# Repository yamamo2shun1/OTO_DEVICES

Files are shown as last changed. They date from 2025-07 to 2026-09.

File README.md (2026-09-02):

# JUMBLEQ

JUMBLEQ logo

[Official Website](https://jumbleq.io/) · [日本語](https://jumbleq.io/ja/)

JUMBLEQ beta prototype

“JUMBLEQ” is short for “jumbled equipment.”

JUMBLEQ is a faderless stereo digital audio mixer that replaces the traditional channel faders found on DJ mixers with magnetic switches. The switches behave like faders while enabling a compact and unconventional control layout.

Each of the two analog stereo inputs and two USB stereo inputs can be routed to Channel Fader A, Channel Fader B, or THRU. The USB audio I/O can also be used as a send/return path, allowing a USB host device to operate as an external effects processor.

As a USB Audio Class 2.0 interface, JUMBLEQ provides 4-in/4-out audio at 24-bit, 48 kHz or 96 kHz. It is USB class-compliant and can be used with Windows, macOS, iPhone, iPad, and Android devices without a device-specific driver.

## Key Features

- Faderless mixing with 10 magnetic switches and 12 potentiometers
- Flexible stereo input routing: assign each of the two analog and two USB inputs to Channel Fader A, Channel Fader B, or THRU
- 4-in/4-out USB Audio Class 2.0 at 24-bit, 48 kHz or 96 kHz
- USB audio send/return routing for external effects processing
- USB MIDI control and the browser-based JUMBLEQ Configurator
- Built-in UF2 bootloader for drag-and-drop firmware updates

## Documentation

See the [JUMBLEQ Documentation](./Docs/README.md) for the complete documentation index.

### User Guide

- [Operation Guide](./Docs/user-guide/operation-guide.md)
- [Firmware update](./Docs/user-guide/firmware-update.md)
- [JUMBLEQ Configurator](./Docs/user-guide/configurator.md)
- [Notes for Windows users](./Docs/user-guide/windows.md)

### Technical Reference

- [Audio specifications](./Docs/reference/audio-spec.md)
- [Hardware and PCB modules](./Docs/reference/hardware.md)
- [Block diagram and audio signal flow](./Docs/reference/signal-flow.md)
- [MIDI reference](./Docs/reference/midi/README.md)

### Development

- [Development environment](./Docs/development/environment.md)
- [STM32CubeIDE projects](./STM32CubeIDE/README.md)
- [SigmaStudio+ project](./SigmaStudio+/README.md)
- [Build and UF2 generation](./Docs/development/build-and-uf2.md)
- [ST-LINK debug configuration](./STM32CubeIDE/docs/Debug_Configuration-STLINK.md)
- [J-Link debug configuration](./STM32CubeIDE/docs/Debug_Configuration-JLINK.md)
- [STM32H7S3 errata](./Docs/development/errata.md)

## Public Website

Visit the [official JUMBLEQ website](https://jumbleq.io/) for an overview of the product, its features, controls, and specifications.

The Astro source is maintained in [`Site`](./Site/) and deployed to GitHub Pages by [the Pages workflow](./.github/workflows/pages.yml).

## Repository Contents

- [`Docs`](./Docs/) — user guides, technical reference, and development notes
- [`Site`](./Site/) — Astro source for the public JUMBLEQ website
- [`STM32CubeIDE`](./STM32CubeIDE/) — MCU application, bootloader, and external memory loader projects
- [`SigmaStudio+`](./SigmaStudio+/) — ADAU1466 DSP project and exported code
- [`Max`](./Max/) — alternative Max Standalone and Max for Live versions of JUMBLEQ Configurator
- [`Plasticity`](./Plasticity/) — enclosure CAD data and printable parts
- [`Logo`](./Logo/) — JUMBLEQ logo and icon artwork
- [`UI_Design`](./UI_Design/) — panel and control-layout artwork

## Related Repositories

- [JUMBLEQ Configurator](https://github.com/yamamo2shun1/JUMBLEQ-Configurator) — browser-based JUMBLEQ Configurator

## Gallery

- [Beta Prototype](./Gallery/beta_prototype.md)
- [Alpha Prototype](./Gallery/alpha_prototype.md)
- [Functional Prototype](./Gallery/functional_prototype.md)
- [Early Prototype](./Gallery/early_prototype.md)
- [Proof of Concept](./Gallery/proof_of_concept.md)

## License

Unless otherwise noted below, this project is licensed under the [MIT License](./LICENSE.md).

- Hardware design sources in [`Plasticity`](./Plasticity/) are licensed under the [CERN Open Hardware Licence Version 2 – Permissive](./Plasticity/LICENSE) (`CERN-OHL-P-2.0`).
- Panel and control-layout design sources in [`UI_Design`](./UI_Design/) are licensed under the [CERN Open Hardware Licence Version 2 – Permissive](./UI_Design/LICENSE) (`CERN-OHL-P-2.0`).

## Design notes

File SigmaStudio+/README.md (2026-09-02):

# SigmaStudio+ Project

This directory contains the SigmaStudio+ project and generated files for the SigmaDSP ADAU1466.

## Updating the DSP Project

After modifying [`JUMBLEQ_DSP.ssprj`](./JUMBLEQ_DSP.ssprj), perform the following operations in SigmaStudio+:

1. Run **Link Compile**.
2. Run **Export System Files**.

The exported files are written to [`exported_code`](./exported_code/).

## Integrating Changes into JUMBLEQ

To include the updated DSP project in JUMBLEQ, copy the following generated header files from [`exported_code`](./exported_code/) to [`STM32CubeIDE/JUMBLEQ/Appli/Core/Inc`](../STM32CubeIDE/JUMBLEQ/Appli/Core/Inc/), replacing the existing files:

- `JUMBLEQ_DSP_ADAU146xSchematic_1.h`
- `JUMBLEQ_DSP_ADAU146xSchematic_1_Defines.h`
- `JUMBLEQ_DSP_ADAU146xSchematic_1_PARAM.h`

## Sample Rate and ASRC Routing

The ADAU1466 DSP core and the AK4619 audio codec interface always operate at 96 kHz. The STM32-to-ADAU1466 serial audio interface follows the USB Audio sample rate and operates at either 48 kHz or 96 kHz.

At 48 kHz, the ADAU1466 ASRCs convert both directions between the STM32-side 48 kHz domain and the DSP-core 96 kHz domain:

```text
STM32 48 kHz -> ASRC input  -> DSP core 96 kHz
STM32 48 kHz <- ASRC output <- DSP core 96 kHz
```

At 96 kHz, the STM32 serial interface and DSP core run at the same sample rate, so the firmware selects the direct paths and bypasses the ASRCs:

```text
STM32 96 kHz -> DSP core 96 kHz
STM32 96 kHz <- DSP core 96 kHz
```

The firmware changes only the STM32-side serial clock and the ASRC/direct routing when the USB sample rate changes. It does not reload the SigmaStudio+ program or change the DSP-core or AK4619 sample rate. Therefore, keep the SigmaStudio+ project configured for 96 kHz and preserve both the direct and ASRC signal paths when modifying the schematic.

## DSP Schematic

### USB Inputs

ss_input1

### Analog Inputs, Line/Phono Selection, Phono EQ and DVS

ss_input2

### Channel Fader Routing

ss_sw1

### THRU Routing

ss_sw2

### Channel Fader Control

ss_fader

### VU Meter Readback

ss_read

### Analog Outputs and Dry/Wet Control

ss_output1

### Headphone Output and Monitor Selection

ss_output2

### USB Outputs and Send Selection

ss_output3

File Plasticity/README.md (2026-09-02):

# JUMBLEQ Enclosure CAD

This directory contains the source and exported CAD data for the JUMBLEQ enclosure, plates, and printable parts.

## License

Copyright (c) 2025 Shunichi Yamamoto.

Unless otherwise noted, the hardware design sources in this directory are licensed under the [CERN Open Hardware Licence Version 2 – Permissive](./LICENSE) (`CERN-OHL-P-2.0`).

You may redistribute and modify these sources and make products using them under the terms of the CERN-OHL-P v2.

These sources are distributed **WITHOUT ANY EXPRESS OR IMPLIED WARRANTY, INCLUDING OF MERCHANTABILITY, SATISFACTORY QUALITY AND FITNESS FOR A PARTICULAR PURPOSE**. See the CERN-OHL-P v2 for applicable conditions.

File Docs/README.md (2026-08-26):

# JUMBLEQ Documentation

This directory contains user guides, technical reference material, and development notes for JUMBLEQ.

## User Guide

- [Operation Guide](./user-guide/operation-guide.md) — controls, signal routing, and device operation
- [Firmware update](./user-guide/firmware-update.md) — update JUMBLEQ using the built-in UF2 bootloader
- [JUMBLEQ Configurator](./user-guide/configurator.md) — change device settings from the Web app or alternative Max versions
- [Notes for Windows users](./user-guide/windows.md) — low-latency audio driver options

## Technical Reference

- [Audio specifications](./reference/audio-spec.md)
- [Hardware](./reference/hardware.md) — main components and PCB modules
- [Signal flow](./reference/signal-flow.md) — hardware block diagram and audio routing
- [MIDI](./reference/midi/README.md) — receive and transmit specifications

## Development

- [Development environment](./development/environment.md)
- [ST-LINK debug configuration](../STM32CubeIDE/docs/Debug_Configuration-STLINK.md)
- [J-Link debug configuration](../STM32CubeIDE/docs/Debug_Configuration-JLINK.md)
- [Build and UF2 generation](./development/build-and-uf2.md)
- [STM32H7S3 errata](./development/errata.md)
- [STM32CubeIDE project overview](../STM32CubeIDE/README.md)

## Project History

See the [Gallery](../Gallery/) for photographs and notes from each prototype stage.

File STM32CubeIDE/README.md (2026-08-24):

# STM32CubeIDE Projects

This STM32CubeIDE workspace contains the firmware projects for the JUMBLEQ hardware.
All projects target the **STM32H7S3Z8T6** on the [STM32H7S3 Development Board](https://github.com/YamamotoWorksDev/STM32H7S3_Dev_Board).

For the debug probe settings used with these projects, see [Debug Configuration for ST-LINK](docs/Debug_Configuration-STLINK.md) and [Debug Configuration for J-Link](docs/Debug_Configuration-JLINK.md). For RTT output, see the J-Link RTT Viewer setup guides for [`JUMBLEQ`](docs/RTT_Viewer-JUMBLEQ.md) and [`LED_BLINK_APP_JLINK`](docs/RTT_Viewer-LED_BLINK_APP_JLINK.md).

## Projects

### `JUMBLEQ`

The main firmware for JUMBLEQ.

- Runs USB, audio, LED, ADC, and OLED processing on FreeRTOS
- Provides USB Audio Class 2.0 and USB MIDI using TinyUSB
- Controls the AK4619 audio codec and ADAU1466 DSP
- Provides the user interface through the OLED, LEDs, and hardware controls
- Saves settings to EEPROM and restores them at startup

The buildable STM32CubeIDE project is located in `JUMBLEQ/Appli`.
The application is configured to run from external flash at `0x90010000`. The post-build step generates BIN and UF2 files. See [J-Link RTT Viewer Setup for JUMBLEQ](docs/RTT_Viewer-JUMBLEQ.md) for its RTT debug output configuration.

### `LED_BLINK_APP`

A minimal test application for verifying basic board operation and application startup from external flash.
It turns LED1 and LED2 on and off in sequence at 500 ms intervals.

The buildable STM32CubeIDE project is located in `LED_BLINK_APP/Appli`.
Like `JUMBLEQ`, the application is configured to run from external flash at `0x90010000`. The post-build step generates a UF2 file.

### `LED_BLINK_APP_JLINK`

A J-Link debug variant of `LED_BLINK_APP` that reports the LED1 and LED2 state changes through SEGGER RTT with timestamps.

The buildable STM32CubeIDE project is located in `LED_BLINK_APP_JLINK/Appli`. The RTT control block is placed in a non-cacheable RAM region so RTT remains coherent while the Cortex-M7 data cache is enabled. See [J-Link RTT Viewer Setup](docs/RTT_Viewer-LED_BLINK_APP_JLINK.md) for the viewer configuration.

### `MX25UW25645GXDI00_STM32H7S3Z8T`

The bootloader and external memory loader for the **MX25UW25645GXDI00** external flash device.

- `Boot`: Bootloader that writes UF2 files over USB Mass Storage Class
  - Enters UF2 update mode when started while SW3 is held down
  - Jumps to the application in external flash during a normal startup
- `ExtMemLoader`: Loader that allows STM32CubeProgrammer and STM32CubeIDE to access the external flash
- `uf2conv.py`: Tool that converts BIN files to UF2 format

#### Boot Build Configuration

The `Boot` project must be built with compiler optimization enabled to fit in the internal flash of the STM32H7S3Z8T6. The `Debug` configuration uses `-O0`, which produces an image that is too large and causes the build to fail. Use the `Release` configuration, which uses `-Os` to optimize the image for size.

In STM32CubeIDE, select `Project > Build Configurations > Set Active > Release` before building the `Boot` project.

For bootloader details, see [`docs/UF2_BOOTLOADER_SPEC.md`](MX25UW25645GXDI00_STM32H7S3Z8T/docs/UF2_BOOTLOADER_SPEC.md).

## Project Relationships

`MX25UW25645GXDI00_STM32H7S3Z8T/Boot` handles startup and firmware updates, then runs `JUMBLEQ/Appli`, `LED_BLINK_APP/Appli`, or `LED_BLINK_APP_JLINK/Appli` from external flash.

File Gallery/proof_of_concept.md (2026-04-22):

# Proof of Concept
DSCF6165-2
DSCF6172-2
DSCF6176-2

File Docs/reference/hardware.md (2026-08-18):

# Hardware

## Main Components

- MCU: [STM32H7S3Z8](https://www.st.com/en/microcontrollers-microprocessors/stm32h7s3z8.html)
- DSP: [ADAU1466](https://www.analog.com/en/products/adau1466.html)
- Audio codec: [AK4619](https://www.akm.com/global/en/products/audio/audio-codec/ak4619vn/)
- Headphone DAC: [TAD5142](https://www.ti.com/product/TAD5142)
- Controls: 10 × [Gateron Low Profile Magnetic Jade Pro](https://www.gateron.com/products/gateron-full-pom-low-profile-magnetic-jade-pro-switch-set) switches and 12 × 10 kΩ potentiometers

## Original PCB Modules

- [STM32H7S3 Development Board](https://github.com/YamamotoWorksDev/STM32H7S3_Dev_Board)
- [AK4619 Audio Module](https://github.com/YamamotoWorksDev/AK4619_Module)
- [TAD5142 Headphone Module](https://github.com/YamamotoWorksDev/TAD5142_Module)
- [Magnetic Switch and Potentiometer Module](https://github.com/YamamotoWorksDev/MagneticSwitch_and_POT_Module)
- [JST PH2 Bus Module](https://github.com/YamamotoWorksDev/JST_PH2_BUS)

## Third-party Modules

- [0.96-inch 128 × 64 OLED display](https://akizukidenshi.com/catalog/g/g112031/)
- [SparkFun Qwiic OLED Display, 0.91-inch 128 × 32](https://www.sparkfun.com/sparkfun-qwiic-oled-display-0-91-in-128x32-lcd-24606.html)
- [SparkFun Qwiic EEPROM Breakout, 512 Kbit](https://www.sparkfun.com/sparkfun-qwiic-eeprom-breakout-512kbit.html)

See [Signal flow](./signal-flow.md) for the relationship between the main hardware blocks.

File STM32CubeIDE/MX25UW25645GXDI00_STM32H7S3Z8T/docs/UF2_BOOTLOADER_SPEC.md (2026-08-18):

# UF2 Bootloader Specification (MX25UW25645GXDI00_STM32H7S3Z8T)

Last updated: 2026-08-17

## Overview

- Target project: `MX25UW25645GXDI00_STM32H7S3Z8T`
- The current system uses a simple configuration that starts an application from external flash using execute-in-place (XIP).
- The UF2 bootloader adds firmware updates over USB Mass Storage Class (MSC).

## Confirmed Requirements

- Enter bootloader mode: power on the device by connecting USB while holding SW3
- USB mode: High Speed (HS)
- Image validation: CRC32 only
- Application location: fixed offset in external flash
- Volume label: `UF2BOOT`
- USB VID/PID: `0x31BF` / `0x0100`

## Purpose

- Receive a UF2 file over USB MSC and write it to the application region in external flash.
- Validate the application using CRC32, then start it using XIP.

## Startup Flow

1. Perform low-level initialization for the clock, MPU, and caches.
2. Initialize XSPI and ExtMem Manager.
3. Select the boot mode.
   - Enter UF2 mode when SW3 is held and USB is connected.
   - Otherwise, start the application.
4. In UF2 mode:
   - Start the USB MSC device.
   - Receive UF2 blocks and write them to external flash.
   - Update the metadata after successful CRC32 validation.
5. In normal mode:
   - Jump to the XIP application.

## Memory Map

- Internal flash
  - Bootloader
- External flash (32 MB = `0x0200_0000`)
  - META region: `0x9000_0000` - `0x9000_FFFF` (64 KB)
  - APP region: `0x9001_0000` - `0x9040_FFFF` (4 MB)
  - Reserved: `0x9041_0000` - `0x91FF_FFFF` (remaining space)

### Fixed Offsets

- `APP_OFFSET = 0x0001_0000` (64 KB)
- `APP_BASE = 0x9000_0000 + APP_OFFSET = 0x9001_0000`
- Set `EXTMEM_XIP_IMAGE_OFFSET` equal to `APP_OFFSET`.
- Set `EXTMEM_HEADER_OFFSET` to `0`.

The META region could be as small as 4 KB, but 64 KB is reserved to align it with an erase-block boundary.

## Erase and Write Strategy

- The device supports 4 KB sector erase and 64 KB block erase operations.
- Erase the APP region in 64 KB blocks to reduce update time.
- Allow 4 KB sector erase operations for small regions such as META.
- When receiving a UF2 file, pre-erase only the 64 KB blocks that correspond to the target address range.

## UF2 Processing

- Receive 512-byte UF2 blocks over USB MSC.
- Map each `targetAddr` to the APP region in external flash.
- Write each block as it is received.
- Calculate CRC32 after all blocks have been received.
- Update META after successful CRC32 validation.

## UF2 MSC Virtual Disk Layout

- Purpose: provide enough capacity to transfer a UF2 file of approximately 8 MB for a 4 MB application
- Disk size: 16 MB (16,384 KB)
- Sector size: 512 bytes
- Cluster size: 1 sector
- File system: FAT16
- Root directory entries: 64
- Volume label: `UF2BOOT`

### Generated Read-only Files

- `INFO_UF2.TXT`
  - Board name, build information, supported address range, and related information
- `INDEX.HTM`
  - Optional link to the product page or update instructions
- `CURRENT.UF2` (optional)
  - Used to read back the current application; omit it if this feature is not required

### Write Acceptance Rules

- Accept only blocks with valid UF2 magic values.
- Write only blocks whose `targetAddr` is within `APP_BASE .. APP_BASE + APP_SIZE - 1`.
- Ignore addresses outside this range and ordinary file-system writes.
- On the first write to an address, erase only the corresponding 64 KB block.
- Use `numBlocks` and `blockNo` to determine when reception is complete, then perform CRC32 validation.

## UF2 Generation and Installation

### Prerequisites

- Application link address: `0x90010000` (`APP_BASE`)
- Use `uf2conv.py` for UF2 conversion.
- Place `uf2families.json` in the same directory as `uf2conv.py`.
- Family ID: `STM32H7RS = 0x6db66083`

### 1. Convert ELF to BIN
```
arm-none-eabi-objcopy -O binary app.elf app.bin
```

### 2. Convert BIN to UF2
```
python uf2conv.py -c -b 0x90010000 -f STM32H7RS -o app.uf2 app.bin
```

### 3. Install the Firmware

1. Hold SW3 while powering on the device by connecting USB.
2. Wait for the `UF2BOOT` volume to mount on the host computer.
3. Drag and drop `app.uf2` onto `UF2BOOT`.
4. After the update completes, the bootloader automatically jumps to the application.

## CRC32 Metadata Specification

### Location

- META base address: `0x9000_0000`
- The first 256 bytes are used for metadata.

### Format (Little-endian)
```
typedef struct {
  uint32_t magic;       // 0x4D544131 ('MTA1')
  uint16_t version;     // 0x0001
  uint16_t header_size; // sizeof(MetaHeader) = 64
  uint32_t flags;       // bit0: valid
  uint32_t app_base;    // 0x90010000
  uint32_t app_size;    // max 0x00400000
  uint32_t app_crc32;   // CRC32 of the entire application
  uint32_t build_id;    // Optional build number or short Git hash
  uint32_t image_size;  // Number of bytes actually written
  uint32_t reserved[6]; // 0
} MetaHeader;
```

### Update Timing

- Calculate CRC32 after the complete UF2 image has been received.
- Update META with `flags.valid = 1` only if CRC32 validation succeeds.
- To update META, erase its 4 KB sector and write the first 256 bytes.

### Validation at Startup

- Check `magic`, `version`, and `header_size` at startup.
- If `flags.valid == 1` and `app_size` is within the maximum size, validate CRC32.
- Start the application using XIP when validation succeeds; enter UF2 mode when validation fails.

## LED Status Patterns

- Normal startup (jump to XIP application): turn on LED0 for 1 second, then turn it off.
- Waiting for UF2 (update mode entered with SW3): blink LED0 slowly at 1 Hz.
- Writing UF2: blink LED1 quickly at 4 Hz.
- Validating CRC32: breathe LED2 at 0.5 Hz.
- Validation successful / preparing to start: turn on LED0, LED1, and LED2 together for 200 ms, then turn them off.
- Validation failed / error: blink LED2 twice for 100 ms each, repeating every second.
- SW3 held without a USB connection (invalid): blink LED1 briefly three times.

## XIP Startup Strategy
- `VTOR = APP_BASE`
- `MSP = *(uint32_t*)APP_BASE`
- `PC  = *(uint32_t*)(APP_BASE + 4)`
- Clean and invalidate the caches before jumping to the application.

## Current Boot Implementation Review (2026-02-12)

- `BOOT_Application()` is implemented in `stm32_boot_xip.c`.
- `MapMemory()` calls `EXTMEM_MemoryMappedMode()` for every memory in `extmem_list_config`.
- If `EXTMEM_MEMORY_BOOTXIP` is unsupported, the bootloader reports `BOOT_ERROR_INCOMPATIBLEMEMORY`.
- `JumpToApplication()` performs the following operations in order:
  - Calls `EXTMEM_GetMapAddress(EXTMEM_MEMORY_BOOTXIP, &Application_vector)`.
  - Adds `EXTMEM_XIP_IMAGE_OFFSET` and `EXTMEM_HEADER_OFFSET`; both are currently undefined and therefore default to `0`.
  - Stops SysTick, I-Cache, and D-Cache.
  - Sets `VTOR`, sets `MSP`, and jumps to `PC`.
- `Boot/Core/Src/main.c` initializes the following components in order:
  - `MX_XSPI1_Init()`
  - `MX_EXTMEM_MANAGER_Init()`
  - `BOOT_Application()`
- The MPU configures the 32 MB region at `0x90000000` as executable and cacheable.
- The linker reserves 64 KB of internal flash starting at `0x08000000` for the bootloader.
- `extmem_list_config` is initialized for NOR SFDP, XSPI1, and 8-line mode.

## Remaining Work

1. Complete the boot-mode selection, USB MSC, UF2 writing, META update, and LED control implementation.

## Implementation Status (2026-02-12)

- Implemented the basic structure for boot-mode selection, UF2 parsing, external flash writes, META updates, and LED control.
- USB MSC operates in High Speed mode using TinyUSB.
- MSC presents a minimal 16 MB FAT16 virtual disk with read-only generated files.
- Confirmed CRC32 validation and the automatic jump to the application after a UF2 update.

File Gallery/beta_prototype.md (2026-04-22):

# Beta Prototype (firmware v0.9.10)
DSCF8296
DSCF8275
DSCF8300
DSCF8299
DSCF8316
DSCF8331

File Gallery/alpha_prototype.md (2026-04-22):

# Alpha Prototype (firmware v0.9.7)







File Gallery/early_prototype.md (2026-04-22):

# Early Prototype
DSCF6407
DSCF6405
DSCF6411
DSCF6414
DSCF6415
DSCF6416

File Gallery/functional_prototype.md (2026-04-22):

# Functional Prototype (firmware v0.9.4)
DSCF6900
DSCF6901
DSCF6902
DSCF6903
DSCF6906
DSCF6908
DSCF6910

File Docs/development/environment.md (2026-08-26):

# Development Environment

The project currently uses the following development tools and packages:

- IDE: [STM32CubeIDE](https://www.st.com/en/development-tools/stm32cubeide.html) 2.2.0
- Code generation and configuration: [STM32CubeMX](https://www.st.com/en/development-tools/stm32cubemx.html) 6.18.1
- Toolchain: GNU Tools for STM32 14.3.rel1.20251027-0700 (GCC 14.3.1)
- UF2 conversion: [Python](https://www.python.org/) 3.13.14
- MCU firmware package: STM32CubeH7RS v1.3.0
- DSP development: [SigmaStudio+](https://www.analog.com/en/resources/evaluation-hardware-and-software/embedded-development-software/sigmastudio-plus.html) 3.4.0
- Legacy Configurator development: [Max](https://cycling74.com/products/max-9) 9.1.5

See the [STM32CubeIDE project overview](../../STM32CubeIDE/README.md) for the firmware projects included in this repository. The Web Configurator is maintained separately in the [JUMBLEQ Configurator repository](https://github.com/yamamo2shun1/JUMBLEQ-Configurator).

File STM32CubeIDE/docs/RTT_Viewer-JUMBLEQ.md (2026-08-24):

# J-Link RTT Viewer Setup for `JUMBLEQ`

This guide describes the J-Link RTT Viewer settings used to monitor debug messages from `JUMBLEQ_Appli`.

## Prerequisites

- Build and program `JUMBLEQ_Appli` with `JUMBLEQ_Appli Debug (JLINK)`.
- Keep the target powered and allow the application to run.
- Install SEGGER J-Link Software and Documentation Pack, including J-Link RTT Viewer.

## Connection Settings

Open J-Link RTT Viewer and use the following configuration.

J-Link RTT Viewer configuration for JUMBLEQ

| Setting | Value |
| --- | --- |
| Connection to J-Link | `USB` |
| SN / Nickname | Disabled unless selecting a specific probe |
| Target Device | `STM32H7S3Z8` |
| Force go on connect | Disabled |
| Script file | Leave empty |
| Target Interface | `SWD` |
| Speed | `4000 kHz` |
| RTT Control Block | `Address` |
| RTT Control Block address | `0x20004200` |

Click **OK** to connect. Channel 0 displays firmware diagnostics while the application is running. The exact messages depend on the connected hardware and runtime activity. For example:

```text
EEPROM CAT24C512 detected on I2C2 (0x50)
[USB] loop=... ready=... idle=... lag=... max_gap=...
```

## Control Block Address

For the current Debug build, select **Address** and enter:

```text
0x20004200
```

In the current Debug build, `_SEGGER_RTT` occupies `0x4B8` bytes in the `.rtt` section starting at `0x20004200`. The linker places this section in DTCM, which is not affected by the Cortex-M7 data cache.

Unlike the fixed address used by `LED_BLINK_APP_JLINK`, the `JUMBLEQ_Appli` address follows the heap and stack allocation and can move when the linker layout changes. After such a change, use **Auto Detection** or confirm `_SEGGER_RTT` in `Debug/JUMBLEQ_Appli.map` and update the address.

## Troubleshooting

- If no output appears, resume the application in STM32CubeIDE; RTT output stops while the CPU is halted.
- Confirm that the selected device is `STM32H7S3Z8` and the interface is `SWD`.
- If the configured address no longer works after a layout change, try **Auto Detection** and check the map file.
- If more than one J-Link is connected, enable **SN / Nickname** and select the intended probe.
- Rebuild the application after changing its linker script, heap size, stack size, or RTT configuration.

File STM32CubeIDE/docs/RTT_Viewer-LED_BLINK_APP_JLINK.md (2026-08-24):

# J-Link RTT Viewer Setup for `LED_BLINK_APP_JLINK`

This guide describes the J-Link RTT Viewer settings used to monitor the LED state messages from `LED_BLINK_APP_JLINK_Appli`.

## Prerequisites

- Build and program `LED_BLINK_APP_JLINK_Appli` with its J-Link Debug configuration.
- Keep the target powered and allow the application to run.
- Install SEGGER J-Link Software and Documentation Pack, including J-Link RTT Viewer.

## Connection Settings

Open J-Link RTT Viewer and use the following configuration.

J-Link RTT Viewer configuration for LED_BLINK_APP_JLINK

| Setting | Value |
| --- | --- |
| Connection to J-Link | `USB` |
| SN / Nickname | Disabled unless selecting a specific probe |
| Target Device | `STM32H7S3Z8` |
| Force go on connect | Disabled |
| Script file | Leave empty |
| Target Interface | `SWD` |
| Speed | `4000 kHz` |
| RTT Control Block | `Address` |
| RTT Control Block address | `0x24071C00` |

Click **OK** to connect. Channel 0 displays messages similar to the following while the application is running:

```text
LED blink started
[0 ms] LED1 ON
[200 ms] LED2 ON
[400 ms] LED1 OFF
[600 ms] LED2 OFF
```

## Why a Fixed Address Is Used

The RTT control block and buffers are linked into the `RW_NONCACHEABLE` region beginning at `0x24071C00`. The application configures this 1 KiB region as non-cacheable before enabling the Cortex-M7 data cache, allowing both the target and J-Link to observe coherent RTT data.

If the RAM layout or linker script changes, confirm the address of `_SEGGER_RTT` in `Debug/LED_BLINK_APP_JLINK_Appli.map` before reconnecting RTT Viewer.

## Troubleshooting

- If no output appears, resume the application in STM32CubeIDE; RTT output stops while the CPU is halted.
- Confirm that the selected device is `STM32H7S3Z8`, the interface is `SWD`, and the control block address is exactly `0x24071C00`.
- If more than one J-Link is connected, enable **SN / Nickname** and select the intended probe.
- Rebuild the application after changing the linker script or RTT configuration.

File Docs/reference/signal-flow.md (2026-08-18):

# Signal Flow

## Hardware Block Diagram

JUMBLEQ hardware block diagram

## Audio Routing and Signal Flow

JUMBLEQ audio routing and signal-flow diagram

See [Audio specifications](./audio-spec.md) for the supported I/O formats and measured analog levels.

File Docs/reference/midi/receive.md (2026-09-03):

# MIDI Receive Specification

This document describes the MIDI receive specification based on the `JUMBLEQ/Appli/Core` implementation as of September 2026.

## 1. Overview

- Incoming MIDI messages are processed over USB MIDI.
- Incoming messages used to change UI settings are accepted only on **MIDI Ch. 15** (1-based channel numbering).

## 2. Program Change (Host -> Device)

### 2.1 Acceptance Conditions

- Program Change messages are accepted only on MIDI Ch. 15.
- Program Change messages on all other channels are ignored.

### 2.2 Program Change Map

| PC Number | Function |
|---:|---|
| 0/1 | Set the Ch. 1 input type (Line / Phono). |
| 2/3 | Set the Ch. 2 input type (Line / Phono). |
| 4/5/6/7 | Assign an input source (Ch. 1 / Ch. 2 / USB[1/2] / USB[3/4]) to Channel Fader A. |
| 8/9/10/11 | Assign an input source (Ch. 1 / Ch. 2 / USB[1/2] / USB[3/4]) to Channel Fader B. |
| 12/13/14/15 | Assign an input source (Ch. 1 / Ch. 2 / USB[1/2] / USB[3/4]) to Post Fader. |
| 16/17 | Disable or enable DVS mode for Ch. 1. |
| 18/19 | Disable or enable DVS mode for Ch. 2. |
| 20/21/22 | Select the Return source (USB[1/2] / USB[3/4] / None). |
| 23/24/25/26 | Select the headphone output source (FADER_A / FADER_B / THRU / MASTER). |
| 27/28 | Assign magnetic switch 2 to the auxiliary fade-down function for Channel Fader A or B. |
| 29/30 | Assign magnetic switch 3 to the auxiliary fade-down function for Channel Fader A or B. |
| 31/32 | Set the Channel Fader A direction (Normal / Reverse). |
| 33/34 | Set the Channel Fader B direction (Normal / Reverse). |
| 120/121 | Disable or enable Channel Fader curve edit mode. |
| 122/123 | Select the output mode (CC / Note) for magnetic controls and channel fader sensors. |
| 126 | Transmit a dump of the parameters currently configured on the device. |
| 127 | Save the current settings to EEPROM. |

Notes:

- `PC22` selects `None`, which disables the Return signal path.
- Auxiliary fade-down assignments for magnetic switches 2 and 3 take effect immediately when the Program Change message is received.
- The default assignments are Channel Fader A for magnetic switch 2 and Channel Fader B for magnetic switch 3.
- Direction can be configured independently for Channel Faders A and B and takes effect immediately. The default is Normal for both faders.
- Reverse inverts the final fader response for Fade Up and all Fade Down controls assigned to that fader, including auxiliary Fade Down controls. It does not change the live MIDI values transmitted by the individual magnetic sensors.
- `PC127` saves the complete device configuration listed in Section 5 to EEPROM, including the DVS enable states, Return and headphone source assignments, magnetic output mode, auxiliary fade-down assignments, Direction settings, and curves for Channel Faders A and B.
- `PC126` transmits the **current operating state (parameters eligible for saving)** rather than reading and transmitting the EEPROM contents.

## 3. Control Change (Host -> Device)

### 3.1 Acceptance Conditions

Control Change messages are accepted only when all of the following conditions are met:

- Channel Fader curve edit mode is enabled.
- The MIDI channel is Ch. 15.
- The CC number is supported (`20` or `21`).

### 3.2 Control Change Map

| CC Number | Parameter | CC Value |
|---:|---|---|
| 20 | `XFADE_CURVE_A` | 0 to 127 |
| 21 | `XFADE_CURVE_B` | 0 to 127 |

Curve response:

- `0` selects the strongest late-rise curve; the level changes mainly near the end of the key travel.
- `64` selects an exactly linear response across the full key travel.
- `127` selects the strongest early-rise curve; the level changes sharply near the start of the key travel.
- The late- and early-rise families use point-reflected exponential curves.
- The default value is `64` for both Channel Faders A and B.

## 4. `curve_edit_mode` (Channel Fader Curve Edit Mode) Behavior

- Use Program Change messages to enable or disable the mode (`PC121` ON / `PC120` OFF).
- While enabled, the main OLED shows the current curve CC values for Channel Faders A and B together with a graphical preview of each curve.
- While disabled, the main OLED uses its normal display and shows the gain values for each input and output channel.
- There is no automatic timeout.

## 5. EEPROM Storage and Startup Restore

- Save trigger: `PC127` on Ch. 15
- Saved parameters:
  - CH1/CH2 input types
  - Channel Fader A/B and Post Fader assignments
  - CH1/CH2 DVS enable states
  - Return source assignment
  - Headphone output source
  - Magnetic output mode (CC / Note)
  - Auxiliary fade-down assignments for magnetic switches 2 and 3
  - Direction settings (Normal / Reverse) for Channel Faders A/B
  - Curve settings for Channel Faders A/B
- EEPROM record version: `0x0007`

## 6. Implementation Notes

- Channel values in the implementation are zero-based (for example, `14` = MIDI Ch. 15).
- The Ch. 15 restrictions for incoming Program Change and Control Change messages are checked in their respective dispatch functions.
- Internally, `CC64` maps to zero exponential curvature. Values below it produce negative (late-rise) curvature, and values above it produce positive (early-rise) curvature. The absolute bipolar curve amount is cubed before it scales the exponent, providing finer adjustment around the linear midpoint while preserving the endpoint curves. The maximum curvature is calibrated so the `CC127` response reaches 90% output at 2% key travel. EEPROM retains the legacy normalized-width representation for backward compatibility; that stored value is converted back to its CC value before the exponential curve is evaluated.

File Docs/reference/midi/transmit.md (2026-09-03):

# MIDI Transmit Specification

This document describes the MIDI transmit specification based on the `JUMBLEQ/Appli/Core` implementation as of September 2026.

## 1. Overview

- Outgoing MIDI messages are sent to the host over USB MIDI.
- Live control output is sent on MIDI Ch. 1.
- Configuration dump responses are sent on MIDI Ch. 15.

## 2. Live Control Output (Device -> Host)

The device transmits the following messages on MIDI Ch. 1. In the implementation, channel value `0` corresponds to MIDI Ch. 1.

| Control | CC Mode | Note Mode | Description |
|---|---|---|---|
| MIDI-assigned potentiometers | CC `0..4` | — | Sends the current knob value. |
| Magnetic controls 0..3 | CC `12..15` | Notes `68..71` | Output mode is selected using `PC122` or `PC123`. |
| Magnetic channel fader sensors 0..5 | CC `20..25` | Notes `60..65` | Output mode is selected using `PC122` or `PC123`. |

In CC mode, magnetic channel fader updates are sent only when the normalized raw value changes by more than `0.01`. This reduces MIDI traffic and jitter.

In Note mode, magnetic controls and channel fader sensors send Note On/Off messages. The peak sensor value measured during the initial 12 ms window is converted to Note On velocity.

CC20 and CC21 have different roles depending on the MIDI channel: on Ch. 1 they carry live values from magnetic channel fader sensors 0 and 1, while on Ch. 15 they carry curve settings for Channel Faders A and B in a configuration dump.

## 3. Implementation Notes

- Channel values in the implementation are zero-based (for example, `0` = MIDI Ch. 1).
- `PC122` selects CC output for magnetic controls and channel fader sensors.
- `PC123` selects Note output for magnetic controls and channel fader sensors.

## 4. Configuration Dump Response (When PC126 Is Received)

When the device receives `PC126` on Ch. 15 from the host, it sends the current values of all parameters eligible for saving back to the host.

- Transmit channel: **MIDI Ch. 15** (implementation value `14`)
- Message types: Program Change and Control Change

### 4.1 Program Change (Device -> Host, Ch. 15)

| PC Value | Meaning |
|---:|---|
| 0/1 | Ch. 1 input type (Line / Phono) |
| 2/3 | Ch. 2 input type (Line / Phono) |
| 4/5/6/7 | Channel Fader A source (Ch. 1 / Ch. 2 / USB[1/2] / USB[3/4]) |
| 8/9/10/11 | Channel Fader B source (Ch. 1 / Ch. 2 / USB[1/2] / USB[3/4]) |
| 12/13/14/15 | Post Fader source (Ch. 1 / Ch. 2 / USB[1/2] / USB[3/4]) |
| 16/17 | Ch. 1 DVS (Off / On) |
| 18/19 | Ch. 2 DVS (Off / On) |
| 20/21/22 | Return source (USB[1/2] / USB[3/4] / None) |
| 23/24/25/26 | Headphone output source (FADER_A / FADER_B / THRU / MASTER) |
| 27/28 | Auxiliary fade-down assignment for magnetic switch 2 (Channel Fader A/B) |
| 29/30 | Auxiliary fade-down assignment for magnetic switch 3 (Channel Fader A/B) |
| 31/32 | Channel Fader A direction (Normal / Reverse) |
| 33/34 | Channel Fader B direction (Normal / Reverse) |
| 122/123 | Output mode for magnetic controls and channel fader sensors (CC / Note) |

The dump contains exactly one value from each Direction pair: `PC31` (Normal) or `PC32` (Reverse) for Channel Fader A, followed by `PC33` (Normal) or `PC34` (Reverse) for Channel Fader B.

### 4.2 Control Change (Device -> Host, Ch. 15)

| CC Number | Meaning |
|---:|---|
| 20 | `XFADE_CURVE_A` (`0` = strongest late rise, `64` = linear, `127` = strongest early rise) |
| 21 | `XFADE_CURVE_B` (`0` = strongest late rise, `64` = linear, `127` = strongest early rise) |

These values use the same scale as incoming curve-edit Control Change messages, allowing the host to restore the current settings directly.

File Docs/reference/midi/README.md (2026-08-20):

# MIDI Reference

JUMBLEQ provides USB MIDI input and output for remote control, configuration, and status reporting.

## Specifications

- [Receive specification](./receive.md) — Program Change and Control Change messages accepted by JUMBLEQ
- [Transmit specification](./transmit.md) — live control output and configuration-dump responses sent by JUMBLEQ

## JUMBLEQ Configurator

The browser-based [JUMBLEQ Configurator](https://configurator.jumbleq.io/) uses these messages to read and change device settings. It is the primary version and receives maintenance priority.

See the [Configurator user guide](../../user-guide/configurator.md) for connection instructions, screenshots, and an overview of the available settings.

The previous Max Standalone and [Max for Live](../../../Max/JUMBLEQ_Configurator.amxd) versions remain available in the [`Max` directory](../../../Max/) for existing workflows.

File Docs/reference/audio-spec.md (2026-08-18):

# Audio Specifications

## I/O and Format

- Analog I/O: 4 inputs, 4 line outputs, and 2 headphone outputs
- USB I/O: 4 inputs and 4 outputs using USB Audio Class 2.0
- USB MIDI: input and output
- Audio format: 24-bit, 48 kHz or 96 kHz

## Line Input

- Input impedance: approximately 25 kΩ
- Test conditions: 1 kHz sine wave, series-resistor method with 10 kΩ

## Line Output

- Nominal output level: -10 dBV (317 mVrms) at LINE OUT 0 dB
- Maximum user output level: 0 dBV / +2.2 dBu (1.0 Vrms) at LINE OUT +10 dB
- Output impedance: approximately 235 Ω
- Test conditions: 1 kHz sine wave, USB input at 0 dBFS, no load

## Headphone Output

- Nominal output level: 281 mVrms into 100 Ω at HP OUT 0 dB
- Maximum output level: 890 mVrms / 7.9 mW into 100 Ω at HP OUT +10 dB
- Output impedance: approximately 9 Ω
- Test conditions: 1 kHz sine wave, 100 Ω load

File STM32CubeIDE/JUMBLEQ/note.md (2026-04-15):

# JUMBLEQ USB Audio 開発メモ

## プロジェクト概要
- **MCU**: STM32H7S3Z8TX (Cortex-M7)
- **USB Stack**: TinyUSB (UAC2)
- **Audio Path**: STM32 ↔ ADAU1466 (DSP) ↔ AK4619 (Codec)
- **サンプルレート**: 48kHz / 96kHz
- **ビット深度**: 24bit

---

# オーディオレイテンシー見積もりメモ (2026-04)

## 対象範囲

この見積もりは、**STM32内部のUSB Audio FIFO <-> バッファ群 <-> SAI** の遅延を対象とする。

含まないもの:
- PC/DAW/ドライバ/ASIOバッファ遅延
- AK4619のADC/DAC群遅延
- ADAU1466のDSPアルゴリズム遅延
- USBホスト側スケジューリングの追加揺らぎ

---

## 見積もり時点の実装条件

- `SAI_RNG_BUF_SIZE = 8192`
- `SAI_TX_BUF_SIZE = 256`
- `SAI_RX_BUF_SIZE = 256`
- `SAI_TX_TARGET_LEVEL_WORDS = 96`
- `audioTask` は `ulTaskNotifyTake(..., 1ms)` で通知待ちしつつ、通知がなくても 1ms ごとに起床
- USB Audio は High-Speed, 4ch, 32bit slot, 48kHz / 96kHz
- USB IN は `audio_frames_per_ms()` により **1ms分まとめて送信**
- USB OUT/IN の TinyUSB SW FIFO はどちらも **約1ms分** (`8 * HS EP size`)
- USB OUT feedback は **FIFO中央水位**を狙う

参考コード:
- `Appli/Core/Inc/audio_control.h`
- `Appli/Core/Src/audio_control.c`
- `Appli/Core/Src/freertos.c`
- `Appli/Core/Inc/tusb_config.h`

---

## 現状の概算レイテンシー

### 1. 再生側 (USB OUT -> SAI OUT)

平均の目安:
- **48kHz: 約 2.3ms**
- **96kHz: 約 1.4ms**

主な内訳:
- USB OUT FIFO目標滞留: 約 `0.5ms`
- TXリング滞留平均:
  - 48kHz: 約 `0.83ms`
  - 96kHz: 約 `0.42ms`
- DMAに積まれてから実際に出るまでの平均:
  - 48kHz: 約 `1.0ms`
  - 96kHz: 約 `0.5ms`

### 2. 録音側 (SAI IN -> USB IN)

平均の目安:
- **48kHz: 約 1.3ms**
- **96kHz: 約 1.0ms**

主な内訳:
- SAI RX から USB送信塊が揃うまで:
  - 48kHz: 約 `0.84ms`
  - 96kHz: 約 `0.51ms`
- USB IN FIFO に 1ms塊を書いた後、ホストへ出るまでの平均: 約 `0.5ms`

### 3. STM32内部の往復 (概算)

- **48kHz: 約 3.7ms**
- **96kHz: 約 2.4ms**

備考:
- 現状は `audioTask` に 1ms タイムアウト起床があるため、平均値とは別に**最大ほぼ1msの追加待ち/ジッタ**が乗る可能性がある。
- したがって、体感差に効くのは平均値よりも**最悪値とジッタ**の方が大きい可能性がある。

---

## 改善余地の見積もり

### A. `SAI_TX_BUF_SIZE` / `SAI_RX_BUF_SIZE` を `256 -> 128` にする

期待できる効果:
- 再生側で約
  - **48kHz: 約 0.67ms短縮**
  - **96kHz: 約 0.33ms短縮**

補足:
- 録音側は現状 `1msまとめ送り` が支配的なため、これ単独では改善幅は比較的小さい。

### B. `SAI_TX_TARGET_LEVEL_WORDS` を下げる

例:
- `96 -> 64 words`
  - 48kHz: 約 `0.17ms` 短縮
  - 96kHz: 約 `0.08ms` 短縮
- `96 -> 32 words`
  - 48kHz: 約 `0.33ms` 短縮
  - 96kHz: 約 `0.17ms` 短縮

補足:
- 再生側専用の改善。
- 下げすぎると underrun 耐性が落ちる。

### C. `audioTask` を完全通知駆動にする

期待できる効果:
- **平均値の短縮は限定的**
- ただし **最大ほぼ1msの余計な待ち** を削れる可能性があり、**ジッタ/最悪値改善**には有効

補足:
- 単体で劇的に短くなるというより、DMA縮小や目標水位低減を安全に進めるための前提として重要。

### D. USB IN を「1msまとめ送り」から細粒度送信にする

期待できる効果:
- 録音側で約
  - **0.3ms から 0.5ms** 短縮見込み

補足:
- 往復でもその分だけ効きやすい。
- 現状の録音側はここが支配的。

### E. USB OUT FIFO目標水位を中央より低くする

期待できる効果:
- 再生側でさらに **約0.25ms前後** 短縮の余地あり

補足:
- 安定性悪化リスクあり。
- 実運用では慎重に詰める必要がある。

---

## 優先度付きの改善順

実装負荷と安全性を考えると、試す順番は以下が妥当。

1. `audioTask` を完全通知駆動に寄せる
2. `SAI_TX_BUF_SIZE` / `SAI_RX_BUF_SIZE` を `128` に下げる
3. `SAI_TX_TARGET_LEVEL_WORDS` を `64` まで下げて評価する
4. USB IN の `1msまとめ送り` をやめて、DMA half/full に近い単位で送る

---

## 現時点での結論

- STM32内部だけを見ると、レイテンシーは**楽器用途として致命的に大きい値ではない**
- 体感遅延により効きやすいのは、STM32内部最適化よりも
  - **PC側のオーディオバッファ設定**
  - **ドライバ/ホストアプリ設定**
  - **DSPアルゴリズム遅延**
  の方である可能性が高い

したがって、システム全体の改善優先度としては、
**まずホスト側バッファ設定を見直し、その後必要ならSTM32内部を詰める**
のが合理的。
```c
volatile uint32_t dbg_usb_isr_count = 0;       // USB ISR呼び出し回数
volatile uint32_t dbg_usb_isr_msp_min = 0xFFFFFFFF;  // ISR中のMSP最小値
volatile uint32_t dbg_usb_isr_msp_start = 0;   // ISR開始時のMSP
```

**freertos.c (vApplicationIdleHook):**
```c
extern size_t dbg_min_free_heap;  // FreeRTOSヒープ空き容量最小値
```

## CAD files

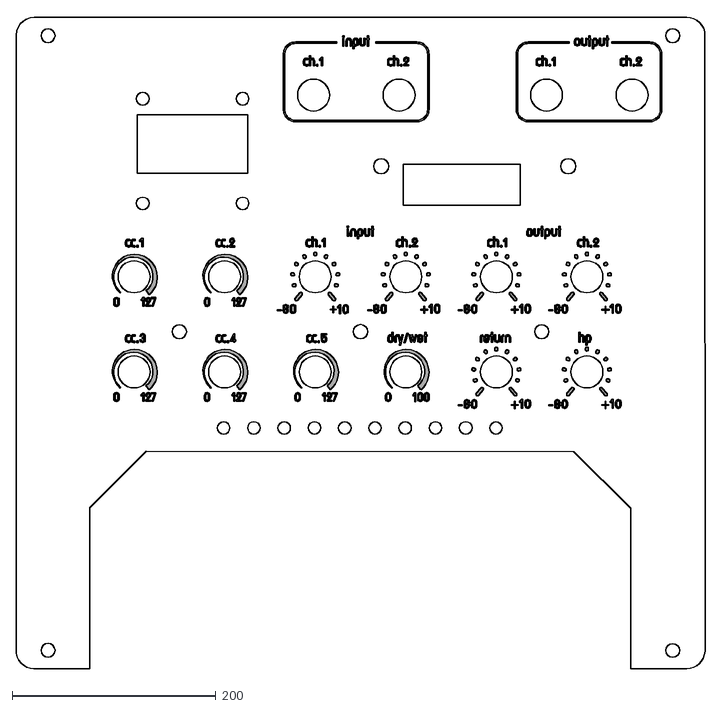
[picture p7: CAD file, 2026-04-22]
UI_Design/JUMBLEQ_top_panel_outline.dxf
676.8 x 641.3

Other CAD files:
Plasticity/key_plate.stp
Plasticity/middle_plate.stp
Plasticity/top_plate.stp
Plasticity/enclosure.stp

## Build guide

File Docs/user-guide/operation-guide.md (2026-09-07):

# Operation Guide

This guide explains JUMBLEQ's physical controls, audio routing, USB signal routing, DVS operation, and OLED indications.

## Signal Routing Overview

Audio sources are assigned to Channel Faders A and B using [JUMBLEQ Configurator](./configurator.md). In standard operation, the Channel Fader A signal is sent to USB 1/2 and the Channel Fader B signal is sent to USB 3/4. Either USB pair can be selected as a Return source and mixed with its corresponding channel-fader signal.

See the [Signal Flow reference](../reference/signal-flow.md) for the detailed audio-routing diagram.

## USB Signal Routing

DVS can be enabled independently for Input Ch. 1 and Input Ch. 2 using [JUMBLEQ Configurator](./configurator.md). The DVS state changes the USB Send source as follows:

| DVS state | Send source | Destination |
|---|---|---|
| Disabled | Channel Fader A (post-fader) | USB 1/2 |
| Disabled | Channel Fader B (post-fader) | USB 3/4 |
| Input Ch. 1 enabled | Input Ch. 1 (pre-fader) | USB 1/2 |
| Input Ch. 2 enabled | Input Ch. 2 (pre-fader) | USB 3/4 |

### When DVS Is Disabled

When DVS is disabled for a USB pair, its corresponding channel-fader signal is sent to the connected USB host as shown in the table above. The Return source can be set to any USB pair whose corresponding DVS setting is disabled, or to None:

| Return setting | Wet signal | Dry signal |
|---|---|---|
| USB 1/2 | USB 1/2 | Channel Fader A (post-fader) |
| USB 3/4 | USB 3/4 | Channel Fader B (post-fader) |
| None | Muted | Channel Faders A and B remain fully dry |

The Dry/Wet knob crossfades the selected Wet signal against its corresponding Dry signal. At 0% the selected path is fully dry; at 100% it is fully wet. The Return knob adjusts the level of the selected Wet signal.

When Return is set to None, Dry is fixed at 100% and Wet at 0%. The Dry/Wet and Return knobs therefore have no effect.

### When DVS Is Enabled

The USB pair corresponding to the enabled DVS channel is used for the DVS send and return path instead of the standard channel-fader Send and selectable Return path. JUMBLEQ Configurator prevents that USB pair from being selected as the Return source.

The Dry/Wet and Return knobs do not control the DVS path. If the other USB pair is not reserved by DVS and is selected as the Return source, both knobs continue to control that Return path normally.

Magnetic-switch changes to a channel fader reach the DSP with a fixed 50 ms control delay when the corresponding input's DVS setting is enabled. Input Ch. 1 and USB 1/2 assignments follow Ch. 1 DVS; Input Ch. 2 and USB 3/4 assignments follow Ch. 2 DVS. This includes PC-return audio assigned directly from USB. The delay follows the input assignment of each fader, including when A and B are swapped. When the corresponding DVS setting is disabled, the fader responds without this additional delay. Magnetic-switch MIDI output retains its existing timing.

Successive fader changes are queued in order, so a brief cut is delayed together with its release. Actual timing also includes the UI task and DSP-write scheduling. Changing the assigned input or its DVS state, or explicitly reapplying fader outputs, cancels pending changes and synchronizes the DSP to the current fader target. The delay is fixed in firmware and is not a Configurator setting.

## Knob Assignments

The following diagram shows the current knob assignments.



### Knob Functions

| Panel label | Range | Function |
|---|---:|---|
| CC.1 | 0–127 | Sends MIDI CC 0 on MIDI Ch. 1. |
| CC.2 | 0–127 | Sends MIDI CC 1 on MIDI Ch. 1. |
| CC.3 | 0–127 | Sends MIDI CC 2 on MIDI Ch. 1. |
| CC.4 | 0–127 | Sends MIDI CC 3 on MIDI Ch. 1. |
| CC.5 | 0–127 | Sends MIDI CC 4 on MIDI Ch. 1. |
| Input Ch. 1 | −80 to +10 dB | Adjusts the level of the analog Channel 1 input before it is routed through the mixer or to the DVS send path. |
| Input Ch. 2 | −80 to +10 dB | Adjusts the level of the analog Channel 2 input before it is routed through the mixer or to the DVS send path. |
| Output Ch. 1 | −80 to +10 dB | Adjusts the level of the analog Channel 1 output. |
| Output Ch. 2 | −80 to +10 dB | Adjusts the level of the analog Channel 2 output. |
| Dry/Wet | 0–100% | Crossfades the selected USB Return signal against its corresponding channel-fader signal. See [USB Signal Routing](#usb-signal-routing). |
| Return | −80 to +10 dB | Adjusts the level of the USB pair selected as the Return source. See [USB Signal Routing](#usb-signal-routing). |
| HP | −80 to +10 dB | Adjusts the headphone output level. |

## Magnetic-switch Assignments



The switches labeled `fade` provide behavior similar to the channel faders on a conventional DJ mixer. Instead of moving a physical fader, key travel changes a virtual fader position according to the current [fader curve setting](#fader-curve-settings). The A fade switches control Channel Fader A, and the B fade switches control Channel Fader B.

The following diagram shows the current magnetic-switch assignments.

### Magnetic-switch Functions

| Panel label | Function |
|---|---|
| A (B) fade down | Controls Channel Fader A (B) in the normal or reverse direction depending on whether the corresponding fade-up switch is held. See [Fade-down Direction](#fade-down-direction). |
| A (B) fade up | Moves Channel Fader A (B) from its current position toward full level. The response follows the corresponding channel-fader curve setting. |
| Aux. A/B (B/A) fade down | Provides an additional fade-down control assignable to Channel Fader A or B using JUMBLEQ Configurator. It follows the same direction behavior as the assigned fader's fade-down switch. See [Auxiliary Fade-down Switches](#auxiliary-fade-down-switches). |
| MIDI CC / Note (4 switches) | Sends MIDI CC 12–15 or Notes 68–71 on MIDI Ch. 1 with a linear response to key travel. The output mode is selected using JUMBLEQ Configurator. |

### Auxiliary Fade-down Switches



The two auxiliary fade-down switches can each be assigned to Channel Fader A or B using JUMBLEQ Configurator. By assigning both auxiliary switches to the same Channel Fader, that fader can be operated with up to three fade-down switches: its main fade-down switch plus the two auxiliary switches.

This arrangement makes rapid multi-click patterns easier to perform, including scratch techniques such as 3-click flares and crab scratches. By default, the A/B auxiliary switch is assigned to Channel Fader A, and the B/A auxiliary switch is assigned to Channel Fader B.

### Fader Curve Settings



The fader curve determines how the key travel of a fade switch is converted to the virtual fader position. Channel Faders A and B can be configured independently using JUMBLEQ Configurator.

| Setting | Response | Style |
|---|---|---|
| 0% | Late-rise response: most of the level change occurs near the end of the key travel. | Long-transition effects |
| 50% | Linear response across the full key travel. | Mixing |
| 100% | Early-rise response: the level rises sharply near the start of the key travel. | Scratching |

Intermediate settings follow a continuous exponential curve. The 0% and 100% responses are exact point reflections of one another around the 50% linear response. The corresponding curve applies to the fade-up and fade-down switches, including any auxiliary fade-down switch assigned to that Channel Fader.

### Fade-down Direction

The A and B fade-down switches change direction depending on whether the matching fade-up switch is held:

| Matching fade-up switch | Pressing fade down | Releasing fade down | Typical use |
|---|---|---|---|
| Not held | Moves the fader toward full level after soft takeover. | Returns the fader to mute after takeover. | Momentary fade-in |
| Held | Moves the fader toward mute. | Restores the level set by the held fade-up switch. | Momentary cut |

When fade up is not held, the fade-down switch uses reversed key travel: its released position represents mute, and pressing it deeper represents a higher level. Soft takeover prevents a sudden level jump by waiting until this reversed value reaches the current fader level before the switch takes control.

This behavior applies independently to Channel Faders A and B. An auxiliary fade-down switch follows the same behavior as the fader to which it is assigned.

See the [MIDI Transmit Specification](../reference/midi/transmit.md) for the MIDI output from all magnetic sensors.

## OLED Indications

The main OLED shows the current sample rate, input and output gains, Return status, and headphone level. The Return indication changes with the selected source:

| Return setting | OLED source indication |
|---|---|
| USB 1/2 | `RTN\|U12` |
| USB 3/4 | `RTN\|U34` |
| None | `RTN\|OFF` |

When USB 1/2 or USB 3/4 is selected, the Return gain is shown after the source indication. When Return is set to None, the gain field shows `---`.

The sub OLED shows the sources assigned to Channel Faders A and B, their input types and DVS states, the post-fader source, and the selected headphone-monitor source. `[D]` indicates that DVS is enabled for the assigned input channel.

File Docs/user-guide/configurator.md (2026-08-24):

# JUMBLEQ Configurator

JUMBLEQ Configurator changes device settings by sending MIDI messages to JUMBLEQ.

## Web App (Recommended)

The browser-based [JUMBLEQ Configurator](https://configurator.jumbleq.io/) is the primary version and receives maintenance priority. It runs without installing a dedicated application; use a browser with Web MIDI support and connect JUMBLEQ to the computer over USB.

[Open JUMBLEQ Configurator](https://configurator.jumbleq.io/)

### Getting Started

1. Connect JUMBLEQ to the computer over USB and power it on.
2. Open the Web app and allow MIDI access when prompted by the browser.
3. Confirm that the connection status shows **JUMBLEQ connected** and that the device settings are synchronized.

The Web app provides controls for input and channel-fader routing, channel-fader response curves, DVS, monitor and Return routing, magnetic-switch behavior, and device settings. It also supports reading the current settings from JUMBLEQ and importing or exporting presets.

### Using the Web App on iPad

Safari does not provide Web MIDI. To connect JUMBLEQ from an iPad:

1. Install [MIDIWeb Browser](https://apps.apple.com/jp/app/midiweb-browser/id6757226617?l=en-US) from the App Store.
2. Connect JUMBLEQ to the iPad over USB and power it on.
3. Open [configurator.jumbleq.io](https://configurator.jumbleq.io/) inside MIDIWeb Browser.
4. Select **Connect device**, allow MIDI access, and wait for the settings to synchronize.

Connection and MIDI communication have been verified with MIDIWeb Browser on iPadOS 26.5.

JUMBLEQ Configurator Web app showing routing and channel-fader settings
<img width="480"" alt="UMBLEQ Configurator Web app showing controls and device settings" src="https://github.com/user-attachments/assets/36ef499a-27e5-489c-96c2-58ebba73b6ec" />

## Alternative Max Versions

The Max Standalone and Max for Live versions remain in the repository for existing workflows, but they have a lower maintenance priority than the Web app. Their source files and packaged versions are available in the [`Max` directory](../../Max/).

### Max Standalone

The Max source patch can be opened with [Max 9](https://cycling74.com/products/max-9). Packaged archives for Windows and macOS are also retained in the `Max` directory.

JUMBLEQ Configurator for Max

### Max for Live

The [Max for Live device](../../Max/JUMBLEQ_Configurator.amxd) allows JUMBLEQ settings to be changed directly from Ableton Live.

JUMBLEQ Configurator for Max for Live

For the MIDI messages used by the configurator, see the [MIDI reference](../reference/midi/README.md).

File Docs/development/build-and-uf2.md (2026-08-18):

# Build and UF2 Generation

JUMBLEQ application projects convert their ELF output to BIN and UF2 files as a post-build step.

## STM32CubeIDE Post-build Command

When creating a new STM32CubeIDE application project, open:

`Project > Properties > C/C++ Build > Settings > Build Steps`

Enter the following command under `Post-build steps > Command`:

```sh
arm-none-eabi-objcopy -O binary "${BuildArtifactFileBaseName}.elf" "${BuildArtifactFileBaseName}.bin" && python "../../../MX25UW25645GXDI00_STM32H7S3Z8T/uf2conv.py" -c -b 0x90010000 -f STM32H7RS -o "${BuildArtifactFileBaseName}.uf2" "${BuildArtifactFileBaseName}.bin"
```

This relative path assumes that the new project is located at the same directory depth as the existing application projects. Adjust the path to `uf2conv.py` if the project is placed elsewhere.

The generated `.bin` and `.uf2` files are written to the active build directory.

STM32CubeIDE post-build command configuration

For instructions on installing the generated firmware, see [Firmware update](../user-guide/firmware-update.md).

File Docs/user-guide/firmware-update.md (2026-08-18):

# Firmware Update

JUMBLEQ includes a built-in UF2 bootloader, so application firmware can be updated without a dedicated programming tool.

## Enter UF2 Bootloader Mode

### Starting from Power Off

1. Make sure JUMBLEQ is powered off.
2. Hold down SW3.
3. While continuing to hold SW3, connect the USB cable.
4. Release SW3 after JUMBLEQ appears as a USB flash drive.

### While JUMBLEQ Is Running

1. Hold down SW3.
2. While continuing to hold SW3, press and release the RESET button.
3. Release SW3 after JUMBLEQ appears as a USB flash drive.

## Install Firmware

Drag and drop the JUMBLEQ `.uf2` firmware file onto the USB drive. The firmware update completes when the file copy finishes.

For information about generating UF2 files from an STM32CubeIDE project, see [Build and UF2 generation](../development/build-and-uf2.md).

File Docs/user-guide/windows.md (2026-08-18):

# Notes for Windows Users

JUMBLEQ is a USB Audio Class 2.0 class-compliant device and does not require a device-specific driver for standard audio operation on Windows.

The project does not currently provide a dedicated ASIO driver. For applications that require an ASIO interface or lower-latency audio routing, use one of the following third-party options:

- [VB-Audio Matrix](https://vb-audio.com/Matrix/)
- [ASIO4ALL](https://asio4all.org/)

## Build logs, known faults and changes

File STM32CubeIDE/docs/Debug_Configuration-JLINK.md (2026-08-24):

# Debug Configuration for J-Link

The following screenshots show the STM32CubeIDE J-Link debug settings used by the firmware projects in this workspace.

### Main
jlink-1

### Debugger
jlink-2

### Startup
jlink-3

## RTT Viewer

- For `JUMBLEQ_Appli`, see [J-Link RTT Viewer Setup for JUMBLEQ](RTT_Viewer-JUMBLEQ.md).
- For `LED_BLINK_APP_JLINK_Appli`, see [J-Link RTT Viewer Setup for LED_BLINK_APP_JLINK](RTT_Viewer-LED_BLINK_APP_JLINK.md).

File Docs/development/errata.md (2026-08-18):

# STM32H7S3 Errata

## Erratum 2.2.15

ST documents the following STM32H7R/S device erratum:

- [I/O compensation could alter the duty cycle of a high-frequency output signal](https://www.st.com/resource/en/errata_sheet/es0596-stm32h7rxx7sxx-device-errata-stmicroelectronics.pdf)

The recommended workaround has already been implemented in the boot-side code:

- [`sbs.c`](../../STM32CubeIDE/MX25UW25645GXDI00_STM32H7S3Z8T/Boot/Core/Src/sbs.c)

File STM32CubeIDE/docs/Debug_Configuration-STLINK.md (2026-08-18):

# Debug Configuration for ST-LINK

The following screenshots show the STM32CubeIDE ST-LINK debug settings used by the firmware projects in this workspace.

### Main
debug_config_main

### Debugger
debug_config_stlink-1
debug_config-stlink-2

### Startup
debug_config_startup

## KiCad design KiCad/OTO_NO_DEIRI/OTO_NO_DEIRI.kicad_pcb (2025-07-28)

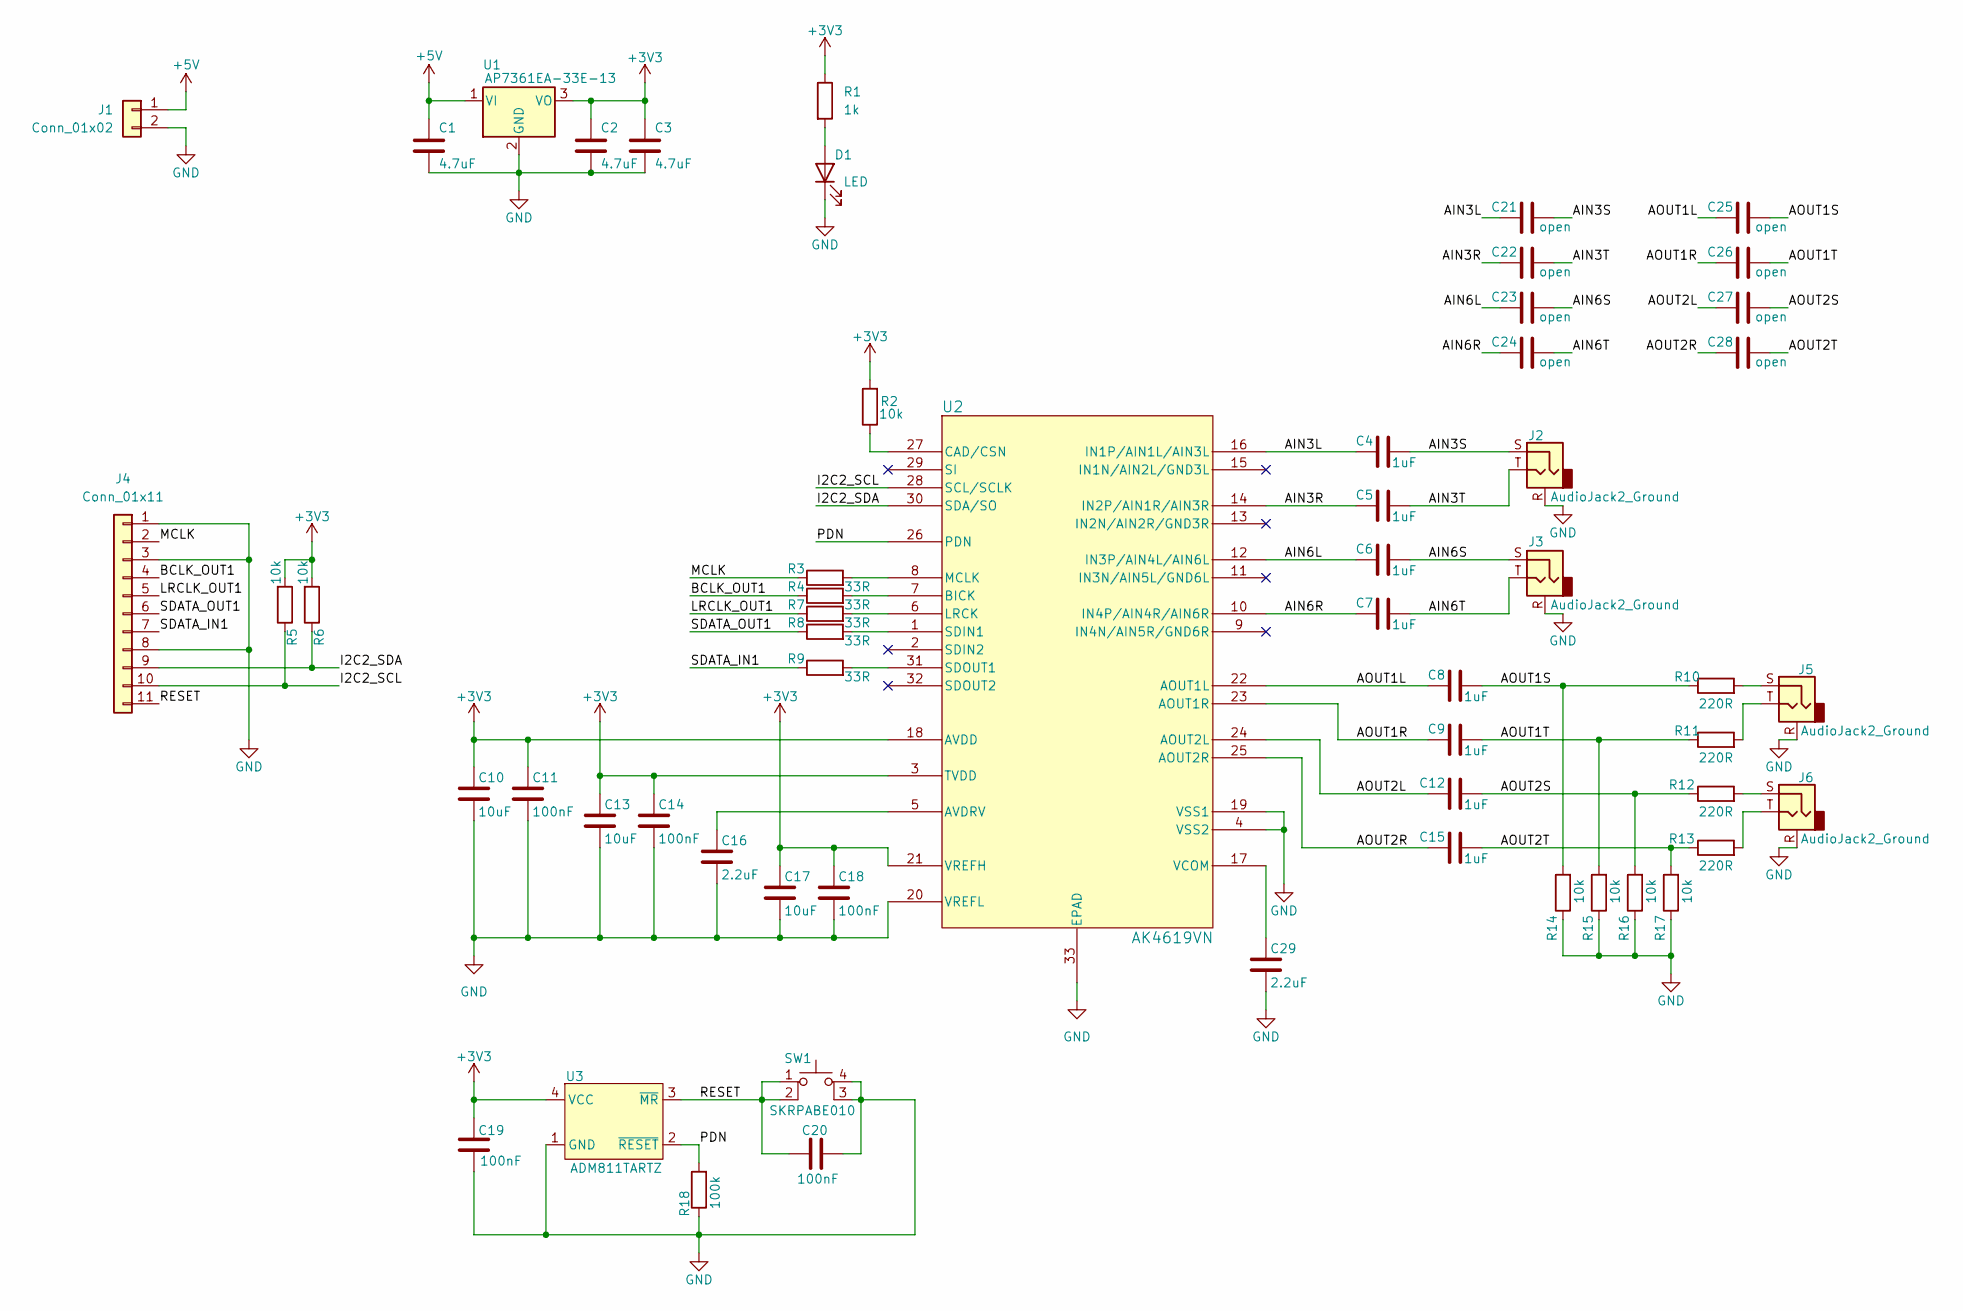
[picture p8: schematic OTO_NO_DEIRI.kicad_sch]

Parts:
C1, C2, C3: 4.7uF; C_0603_1608Metric
C4, C5, C6, C7, C8, C9, C12, C15: 1uF; C_1210_3225Metric_Pad1.33x2.70mm_HandSolder
C10, C13, C17: 10uF; C_0402_1005Metric
C11, C14, C18: 100nF; C_0201_0603Metric
C16, C29: 2.2uF; C_0201_0603Metric
C19, C20: 100nF; C_0402_1005Metric
C21, C22, C23, C24, C25, C26, C27, C28: open; C_1812_4532Metric_Pad1.57x3.40mm_HandSolder
D1: LED; LED_0603_1608Metric
J1: Conn_01x02; JST_PH_S2B-PH-K_1x02_P2.00mm_Horizontal
J2, J3, J5, J6: AudioJack2_Ground; Jack_3.5mm_QingPu_WQP-PJ366ST_Vertical
J4: Conn_01x11; PinSocket_1x11_P2.54mm_Vertical
R1: 1k; R_0201_0603Metric
R2, R5, R6: 10k; R_0201_0603Metric
R3, R4, R7, R8, R9: 33R; R_0201_0603Metric
R10, R11, R12, R13: 220R; R_0603_1608Metric_Pad0.98x0.95mm_HandSolder
R14, R15, R16, R17: 10k; R_0201_0603Metric_Pad0.64x0.40mm_HandSolder
R18: 100k; R_0201_0603Metric
SW1: SKRPABE010
U1: AP7361EA-33E-13; SOT-223-3_TabPin2
U2: AK4619VN; AK4619VN_AKM
U3: ADM811TARTZ; SOT-143

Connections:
+3V3: C2.1, C3.1, C10.1, C11.1, C13.1, C14.1, C17.1, C18.1, C19.1, R1.1, R2.2, R5.2, R6.2, U1.3 (VO), U2.3 (TVDD), U2.18 (AVDD), U2.21 (VREFH), U3.4 (VCC)
+5V: C1.1, J1.1, U1.1 (VI)
/AIN3L: C4.1, C21.1, U2.16 (IN1P/AIN1L/AIN3L)
/AIN3R: C5.1, C22.1, U2.14 (IN2P/AIN1R/AIN3R)
/AIN3S: C4.2, C21.2, J2.S
/AIN3T: C5.2, C22.2, J2.T
/AIN6L: C6.1, C23.1, U2.12 (IN3P/AIN4L/AIN6L)
/AIN6R: C7.1, C24.1, U2.10 (IN4P/AIN4R/AIN6R)
/AIN6S: C6.2, C23.2, J3.S
/AIN6T: C7.2, C24.2, J3.T
/AOUT1L: C8.1, C25.1, U2.22 (AOUT1L)
/AOUT1R: C9.1, C26.1, U2.23 (AOUT1R)
/AOUT1S: C8.2, C25.2, R10.1, R14.2
/AOUT1T: C9.2, C26.2, R11.1, R15.2
/AOUT2L: C12.1, C27.1, U2.24 (AOUT2L)
/AOUT2R: C15.1, C28.1, U2.25 (AOUT2R)
/AOUT2S: C12.2, C27.2, R12.1, R16.2
/AOUT2T: C15.2, C28.2, R13.1, R17.2
/BCLK_OUT1: J4.4, R4.1
/I2C2_SCL: J4.10, R5.1, U2.28 (SCL/SCLK)
/I2C2_SDA: J4.9, R6.1, U2.30 (SDA/SO)
/LRCLK_OUT1: J4.5, R7.1
/MCLK: J4.2, R3.1
/PDN: R18.2, U2.26 (PDN), U3.2 (~RESET)
/RESET: C20.1, J4.11, SW1.1, SW1.2, U3.3 (~MR)
/SDATA_IN1: J4.7, R9.1
/SDATA_OUT1: J4.6, R8.1
GND: C1.2, C2.2, C3.2, C10.2, C11.2, C13.2, C14.2, C16.2, C17.2, C18.2, C19.2, C20.2, C29.2, D1.1 (K), J1.2, J2.R, J3.R, J4.1, J4.3, J4.8, J5.R, J6.R, R14.1, R15.1, R16.1, R17.1, R18.1, SW1.3 (K), SW1.4 (A), U1.2 (GND), U2.4 (VSS2), U2.19 (VSS1), U2.20 (VREFL), U2.33 (EPAD), U3.1 (GND)
unnamed: D1.2 (A), R1.2
unnamed: J5.S, R10.2
unnamed: J5.T, R11.2
unnamed: J6.S, R12.2
unnamed: J6.T, R13.2
unnamed: C16.1, U2.5 (AVDRV)
unnamed: R4.2, U2.7 (BICK)
unnamed: R2.1, U2.27 (CAD/CSN)
unnamed: R7.2, U2.6 (LRCK)
unnamed: R3.2, U2.8 (MCLK)
unnamed: R8.2, U2.1 (SDIN1)
unnamed: R9.2, U2.31 (SDOUT1)
unnamed: C29.1, U2.17 (VCOM)

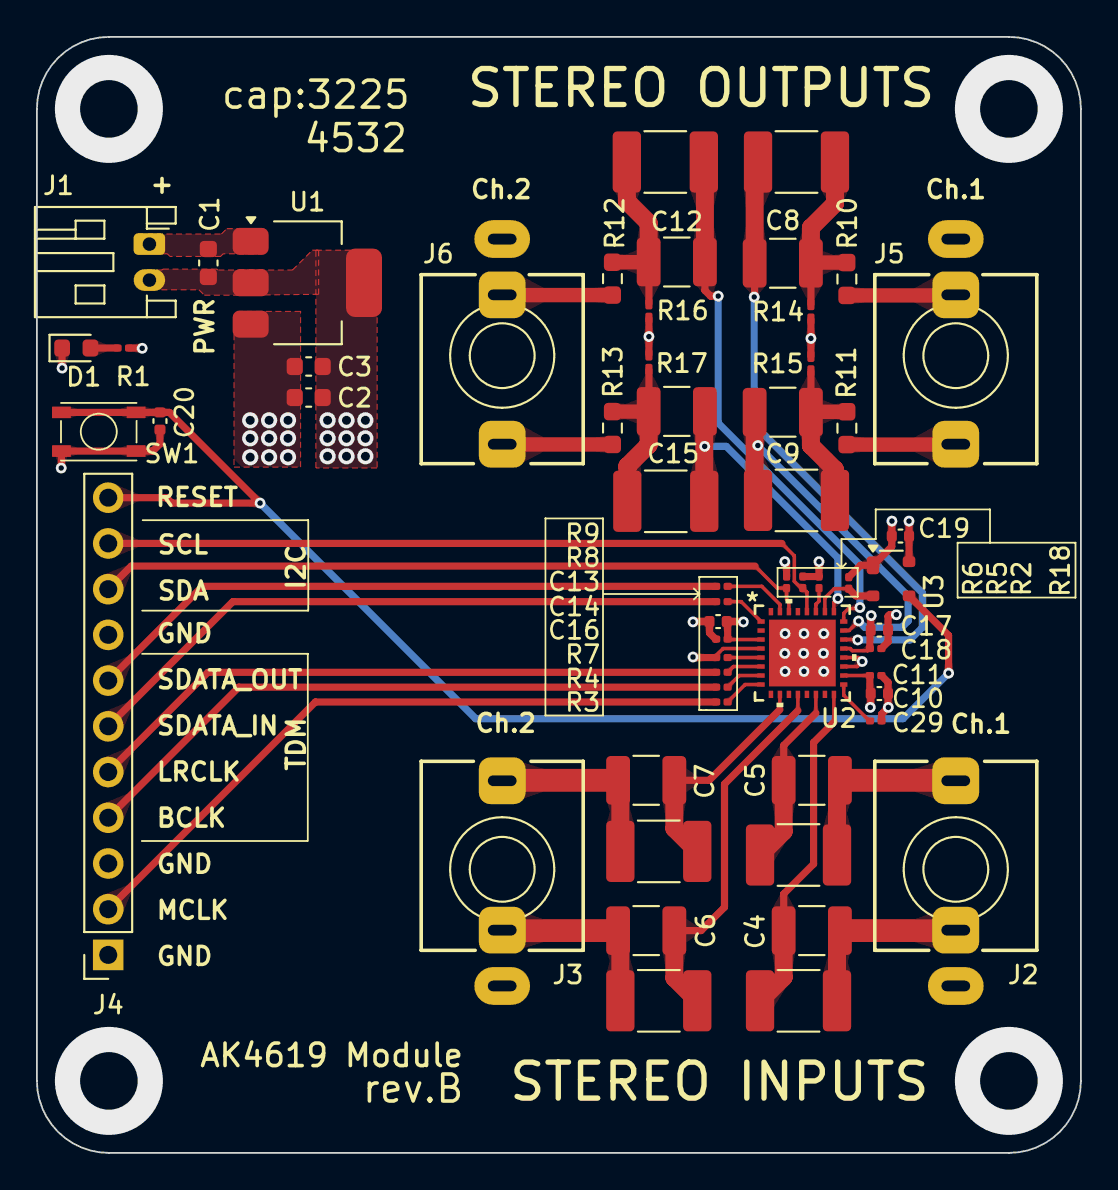
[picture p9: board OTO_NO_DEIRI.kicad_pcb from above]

Board: 4 copper layers, 58.0 x 62.0 mm, 58 parts (0 on the bottom side), 41 nets.

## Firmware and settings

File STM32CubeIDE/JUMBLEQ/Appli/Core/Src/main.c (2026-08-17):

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
/* Includes ------------------------------------------------------------------*/
#include "main.h"
#include "FreeRTOS.h"
#include "cmsis_os2.h"
#include "adc.h"
#include "gpdma.h"
#include "hpdma.h"
#include "i2c.h"
#include "sai.h"
#include "spi.h"
#include "tim.h"
#include "usb_otg.h"
#include "gpio.h"

/* USER CODE BEGIN Includes */
#include "audio_control.h"
#include "eeprom.h"
#include "led_control.h"
/* USER CODE END Includes */


void MX_FREERTOS_Init(void);
/* USER CODE BEGIN PFP */
static void MPU_Config(void);
/* USER CODE END PFP */

/* USER CODE BEGIN 0 */
int __io_putchar(uint8_t ch)
{
    return ITM_SendChar(ch);
}

static void DWT_Init(void)
{
    /* Enable DWT cycle counter for timing measurements */
    CoreDebug->DEMCR |= CoreDebug_DEMCR_TRCENA_Msk;
    DWT->CYCCNT = 0;
    DWT->CTRL |= DWT_CTRL_CYCCNTENA_Msk;
}

void HAL_GPIO_EXTI_Callback(uint16_t GPIO_Pin)
{
    if (GPIO_Pin == UCPD_FLG_n_Pin)
    {
        HAL_GPIO_WritePin(UCPD_PWR_EN_GPIO_Port, UCPD_PWR_EN_Pin, GPIO_PIN_RESET);
    }
}

/* USER CODE END 0 */

/**
  * @brief  The application entry point.
  * @retval int
  */
int main(void)
{

  /* USER CODE BEGIN 1 */
    /* MPU Configuration--------------------------------------------------------*/
    MPU_Config();
  /* USER CODE END 1 */

  /* Enable the CPU Cache */

  /* Enable I-Cache---------------------------------------------------------*/
  SCB_EnableICache();

  /* Enable D-Cache---------------------------------------------------------*/
  SCB_EnableDCache();

  /* MCU Configuration--------------------------------------------------------*/

  /* Update SystemCoreClock variable according to RCC registers values. */
  SystemCoreClockUpdate();

  /* Reset of all peripherals, Initializes the Flash interface and the Systick. */
  HAL_Init();

  /* USER CODE BEGIN SysInit */
    DWT_Init();

  /* USER CODE END SysInit */

  /* Initialize all configured peripherals */
  MX_GPIO_Init();
  MX_GPDMA1_Init();
  MX_HPDMA1_Init();
  MX_USB_OTG_HS_PCD_Init();
  MX_I2C3_Init();
  MX_SPI5_Init();
  MX_SAI1_Init();
  MX_TIM1_Init();
  MX_SAI2_Init();
  MX_ADC1_Init();
  MX_I2C2_Init();
  MX_ADC2_Init();
  /* USER CODE BEGIN 2 */
    if (EEPROM_CheckConnection(&hi2c2) == HAL_OK)
    {
        SEGGER_RTT_printf(0, "EEPROM CAT24C512 detected on I2C2 (0x50)\r\n");
    }
    else
    {
        SEGGER_RTT_printf(0, "EEPROM CAT24C512 not detected on I2C2 (0x50)\r\n");
        Error_Handler();
    }

  /* USER CODE END 2 */

  /* Init scheduler */
  osKernelInitialize();  /* Call init function for freertos objects (in cmsis_os2.c) */
  MX_FREERTOS_Init();

  /* Start scheduler */
  osKernelStart();

  /* We should never get here as control is now taken by the scheduler */

  /* Infinite loop */
  /* USER CODE BEGIN WHILE */
    while (1)
    {
    /* USER CODE END WHILE */

    /* USER CODE BEGIN 3 */
        // FreeRTOS使用時はここに到達しない
        // すべての処理はタスク（freertos.c）で実行される
    }
  /* USER CODE END 3 */
}

/* USER CODE BEGIN 4 */
/* MPU Configuration */
static void MPU_Config(void)
{
    MPU_Region_InitTypeDef MPU_InitStruct = {0};

    /* Disable the MPU */
    HAL_MPU_Disable();

    /* Region 0: default no access for undefined regions */
    MPU_InitStruct.Enable           = MPU_REGION_ENABLE;
    MPU_InitStruct.Number           = MPU_REGION_NUMBER0;
    MPU_InitStruct.BaseAddress      = 0x00000000;
    MPU_InitStruct.Size             = MPU_REGION_SIZE_4GB;
    MPU_InitStruct.SubRegionDisable = 0x87;
    MPU_InitStruct.TypeExtField     = MPU_TEX_LEVEL0;
    MPU_InitStruct.AccessPermission = MPU_REGION_NO_ACCESS;
    MPU_InitStruct.DisableExec      = MPU_INSTRUCTION_ACCESS_DISABLE;
    MPU_InitStruct.IsShareable      = MPU_ACCESS_NOT_SHAREABLE;
    MPU_InitStruct.IsCacheable      = MPU_ACCESS_NOT_CACHEABLE;
    MPU_InitStruct.IsBufferable     = MPU_ACCESS_NOT_BUFFERABLE;
    HAL_MPU_ConfigRegion(&MPU_InitStruct);

    /* Region 1: external XSPI flash (XIP) */
    MPU_InitStruct.Enable           = MPU_REGION_ENABLE;
    MPU_InitStruct.Number           = MPU_REGION_NUMBER1;
    MPU_InitStruct.BaseAddress      = 0x90000000;
    MPU_InitStruct.Size             = MPU_REGION_SIZE_32MB;
    MPU_InitStruct.SubRegionDisable = 0x00;
    MPU_InitStruct.AccessPermission = MPU_REGION_FULL_ACCESS;
    MPU_InitStruct.DisableExec      = MPU_INSTRUCTION_ACCESS_ENABLE;
    MPU_InitStruct.IsCacheable      = MPU_ACCESS_CACHEABLE;
    MPU_InitStruct.IsBufferable     = MPU_ACCESS_BUFFERABLE;
    HAL_MPU_ConfigRegion(&MPU_InitStruct);

    /* Region 2: AXI SRAM */
    MPU_InitStruct.Number      = MPU_REGION_NUMBER2;
    MPU_InitStruct.BaseAddress = 0x24000000;
    MPU_InitStruct.Size        = MPU_REGION_SIZE_256KB;
    MPU_InitStruct.DisableExec = MPU_INSTRUCTION_ACCESS_DISABLE;
    HAL_MPU_ConfigRegion(&MPU_InitStruct);

    /* Region 3: noncacheable buffer */
    MPU_InitStruct.Number       = MPU_REGION_NUMBER3;
    MPU_InitStruct.BaseAddress  = 0x24040000;
    MPU_InitStruct.Size         = MPU_REGION_SIZE_256KB;
    MPU_InitStruct.TypeExtField = MPU_TEX_LEVEL1;
    MPU_InitStruct.IsCacheable  = MPU_ACCESS_NOT_CACHEABLE;
    MPU_InitStruct.IsBufferable = MPU_ACCESS_NOT_BUFFERABLE;
    HAL_MPU_ConfigRegion(&MPU_InitStruct);

    /* Enable the MPU */
    HAL_MPU_Enable(MPU_PRIVILEGED_DEFAULT);
}
/* USER CODE END 4 */

/**
  * @brief  Period elapsed callback in non blocking mode
  * @note   This function is called  when TIM6 interrupt took place, inside
  * HAL_TIM_IRQHandler(). It makes a direct call to HAL_IncTick() to increment
  * a global variable "uwTick" used as application time base.
  * @param  htim TIM handle
  * @retval None
  */
void HAL_TIM_PeriodElapsedCallback(TIM_HandleTypeDef* htim)
{
    if (htim->Instance == TIM6)
    {
    HAL_IncTick();
  }
}

/**
  * @brief  This function is executed in case of error occurrence.
  * @retval None
  */
void Error_Handler(void)
{
  /* USER CODE BEGIN Error_Handler_Debug */
    /* User can add his own implementation to report the HAL error return state */
    __disable_irq();
    while (1)
    {
    }
  /* USER CODE END Error_Handler_Debug */
}
#ifdef USE_FULL_ASSERT
/**
  * @brief  Reports the name of the source file and the source line number
  *         where the assert_param error has occurred.
  * @param  file: pointer to the source file name
  * @param  line: assert_param error line source number
  * @retval None
  */
void assert_failed(uint8_t* file, uint32_t line)
{
  /* USER CODE BEGIN 6 */
    /* User can add his own implementation to report the file name and line number,
       ex: printf("Wrong parameters value: file %s on line %d\r\n", file, line) */
  /* USER CODE END 6 */
}
#endif /* USE_FULL_ASSERT */

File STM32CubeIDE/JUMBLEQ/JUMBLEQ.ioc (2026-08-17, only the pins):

Mcu.UserName=STM32H7S3Z8Tx
PA0.Signal=ADCx_INP0
PA10.Signal=S_TIM1_CH3
PA13(JTMS/SWDIO).Signal=DEBUG_JTMS-SWDIO
PA14(JTCK/SWCLK).Signal=DEBUG_JTCK-SWCLK
PA3.Signal=ADCx_INP15
PA4.Signal=ADC1_INP18
PA5.Signal=ADC2_INP18
PA6.Signal=ADCx_INP3
PA8.Signal=I2C3_SCL
PA9.Signal=I2C3_SDA
PB1.Signal=ADCx_INP5
PB10.Signal=I2C2_SCL
PB11.Signal=I2C2_SDA
PB12.GPIO_Label=S3
PB12.Signal=GPIO_Output
PB13.GPIO_Label=CODEC_RESET
PB13.Signal=GPIO_Output
PC0.Signal=ADCx_INP10
PC2.Signal=ADCx_INP12
PC3.Signal=ADCx_INP13
PC9.Signal=I2S_CKIN
PD0.GPIO_Label=LED2
PD0.Signal=GPIO_Output
PD1.GPIO_Label=LED1
PD1.Signal=GPIO_Output
PD10.GPIO_Label=S2
PD10.Signal=GPIO_Output
PD11.Signal=SAI2_SD_A
PD12.Signal=SAI2_FS_A
PD13.Signal=SAI2_SCK_A
PD14.GPIO_Label=SW2
PD14.Signal=GPIO_Input
PD15.GPIO_Label=SW1
PD15.Signal=GPIO_Input
PD2.GPIO_Label=LED0
PD2.Signal=GPIO_Output
PD8.GPIO_Label=S0
PD8.Signal=GPIO_Output
PD9.GPIO_Label=S1
PD9.Signal=GPIO_Output
PE4.Signal=SAI1_FS_A
PE5.Signal=SAI1_SCK_A
PE6.Signal=SAI1_SD_A
PH0-OSC_IN(PH0).Signal=RCC_OSC_IN
PH1-OSC_OUT(PH1).GPIO_Label=DSP_RESET
PH1-OSC_OUT(PH1).Signal=GPIO_Output

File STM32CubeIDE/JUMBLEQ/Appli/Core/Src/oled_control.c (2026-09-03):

/*
 * oled_control.c
 *
 *  Created on: 2026/01/26
 *      Author: Shnichi Yamamoto
 */

#include "main_oled.h"
#include "sub_oled.h"
#include "oled_control.h"
#include "app_version.h"

#include "audio_control.h"
#include "ssd1306_fonts.h"
#include "cmsis_os2.h"
#include <stdbool.h>
#include <stdio.h>
#include <string.h>

static void draw_sub_headphones_icon(uint8_t x, uint8_t y);
static void draw_main_headphones_icon(uint8_t x, uint8_t y);
static void draw_main_ch_fader_curve_preview(uint8_t x, uint8_t y, uint8_t width, uint8_t height, uint8_t cc_value);

static void draw_main_ch_fader_curve_preview(uint8_t x, uint8_t y, uint8_t width, uint8_t height, uint8_t cc_value)
{
    if ((width < 2U) || (height < 2U))
    {
        return;
    }

    uint8_t prev_x = x;
    uint8_t prev_y = (uint8_t) (y + height - 1U);

    for (uint8_t i = 0U; i < width; i++)
    {
        const float position = (float) i / (float) (width - 1U);
        const float gain     = ui_control_evaluate_ch_fader_curve_preview(cc_value, position);
        const uint8_t current_x = (uint8_t) (x + i);
        const uint8_t current_y = (uint8_t) (y + height - 1U - (uint8_t) (gain * (float) (height - 1U)));

        if (i > 0U)
        {
            main_oled_Line(prev_x, prev_y, current_x, current_y, White);
        }

        prev_x = current_x;
        prev_y = current_y;
    }
}

static void merge_dirty_pages(bool* dirty, uint8_t* dirty_start_page, uint8_t* dirty_end_page, uint8_t page_start, uint8_t page_end)
{
    if (!*dirty)
    {
        *dirty            = true;
        *dirty_start_page = page_start;
        *dirty_end_page   = page_end;
        return;
    }

    if (*dirty_start_page > page_start)
    {
        *dirty_start_page = page_start;
    }
    if (*dirty_end_page < page_end)
    {
        *dirty_end_page = page_end;
    }
}

static void update_sub_text_block(char* prev, size_t prev_size, const char* text, uint8_t clear_x1, uint8_t clear_y1, uint8_t clear_x2, uint8_t clear_y2, uint8_t cursor_x, uint8_t cursor_y, uint8_t page_start, uint8_t page_end, bool* dirty, uint8_t* dirty_start_page, uint8_t* dirty_end_page)
{
    if (strcmp(prev, text) == 0)
    {
        return;
    }

    sub_oled_FillRectangle(clear_x1, clear_y1, clear_x2, clear_y2, Black);
    sub_oled_SetCursor(cursor_x, cursor_y);
    sub_oled_WriteString((char*) text, Font_7x10, White);
    snprintf(prev, prev_size, "%s", text);

    merge_dirty_pages(dirty, dirty_start_page, dirty_end_page, page_start, page_end);
}

static void update_sub_dvs_badge(bool show, bool enabled, uint8_t x, uint8_t y, bool* prev_show, bool* prev_enabled, bool* dirty, uint8_t* dirty_start_page, uint8_t* dirty_end_page)
{
    if ((*prev_show == show) && (!show || (*prev_enabled == enabled)))
    {
        return;
    }

    // "[D]" / "[ ]" in Font_7x10 requires ~3 chars width.
    sub_oled_FillRectangle(x, y, (uint8_t) (x + 20U), (uint8_t) (y + 9U), Black);

    if (show)
    {
        sub_oled_SetCursor(x, y);
        sub_oled_WriteString(enabled ? "[D]" : "[ ]", Font_7x10, White);
    }

    *prev_show    = show;
    *prev_enabled = enabled;
    merge_dirty_pages(dirty, dirty_start_page, dirty_end_page, 0, 1);
}

static void update_sub_reverse_indicators(bool reverse_a, bool reverse_b, bool* prev_reverse_a, bool* prev_reverse_b, bool* dirty, uint8_t* dirty_start_page, uint8_t* dirty_end_page)
{
    if (*prev_reverse_a != reverse_a)
    {
        sub_oled_FillRectangle(0, 15, 55, 26, Black);
        if (reverse_a)
        {
            sub_oled_SetCursor(0, 17);
            sub_oled_WriteString("R", Font_7x10, White);
            sub_oled_FillRectangle(8, 22, 55, 20, White);
        }
        else
        {
            sub_oled_FillRectangle(5, 22, 55, 20, White);
        }

        *prev_reverse_a = reverse_a;
        merge_dirty_pages(dirty, dirty_start_page, dirty_end_page, 1, 3);
    }

    if (*prev_reverse_b != reverse_b)
    {
        sub_oled_FillRectangle(73, 15, 127, 26, Black);
        if (reverse_b)
        {
            sub_oled_FillRectangle(73, 22, 119, 20, White);
            sub_oled_SetCursor(121, 17);
            sub_oled_WriteString("R", Font_7x10, White);
        }
        else
        {
            sub_oled_FillRectangle(73, 22, 123, 20, White);
        }

        *prev_reverse_b = reverse_b;
        merge_dirty_pages(dirty, dirty_start_page, dirty_end_page, 1, 3);
    }
}

static void update_sub_bottom_status(char* prev_srcP, size_t prev_srcP_size, char* prev_hp_src, size_t prev_hp_src_size, const char* srcP, const char* hp_src, bool* dirty, uint8_t* dirty_start_page, uint8_t* dirty_end_page)
{
    const bool srcP_changed   = (strcmp(prev_srcP, srcP) != 0);
    const bool hp_src_changed = (strcmp(prev_hp_src, hp_src) != 0);

    if (!srcP_changed && !hp_src_changed)
    {
        return;
    }

    // Treat the bottom row as one unit so overlapping redraw regions never erase the HP label.
    sub_oled_FillRectangle(0, 50, 127, 59, Black);
    sub_oled_SetCursor(1, 50);
    sub_oled_WriteString((char*) srcP, Font_7x10, White);
    draw_sub_headphones_icon(103, 50);
    sub_oled_SetCursor(120, 51);
    sub_oled_WriteString((char*) hp_src, Font_7x10, White);

    snprintf(prev_srcP, prev_srcP_size, "%s", srcP);
    snprintf(prev_hp_src, prev_hp_src_size, "%s", hp_src);
    merge_dirty_pages(dirty, dirty_start_page, dirty_end_page, 6, 7);
}

static const char* nonnull_str(const char* text)
{
    return (text == NULL) ? "" : text;
}

static uint16_t oled_text_width_px(SSD1306_Font_t const* font, const char* text)
{
    if ((font == NULL) || (text == NULL))
    {
        return 0U;
    }

    uint16_t width = 0U;
    for (size_t i = 0; text[i] != '\0'; i++)
    {
        char c = text[i];
        if ((font->char_width != NULL) && (c >= 32) && (c <= 126))
        {
            width = (uint16_t) (width + font->char_width[(uint8_t) c - 32U]);
        }
        else
        {
            width = (uint16_t) (width + font->width);
        }
    }

    return width;
}

static const unsigned char headphones_icon_16x10[] = {
    0x03, 0xC0, // 00000011 11000000
    0x0E, 0x70, // 00001110 01110000
    0x18, 0x18, // 00011000 00011000
    0x30, 0x0C, // 00110000 00001100
    0x20, 0x04, // 00100000 00000100
    0x20, 0x04, // 00100000 00000100
    0x36, 0x6C, // 00110110 01101100
    0x3E, 0x7C, // 00111110 01111100
    0x1E, 0x78, // 00011110 01111000
    0x0E, 0x70, // 00001110 01110000
};

static void draw_sub_headphones_icon(uint8_t x, uint8_t y)
{
    sub_oled_DrawBitmap(x, y, headphones_icon_16x10, 16, 10, White);
}

static void draw_main_headphones_icon(uint8_t x, uint8_t y)
{
    main_oled_DrawBitmap(x, y, headphones_icon_16x10, 16, 10, White);
}
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

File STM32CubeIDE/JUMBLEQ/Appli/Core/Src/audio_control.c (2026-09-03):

/*
 * audio_control.c
 *
 *  Created on: Nov 13, 2025
 *      Author: Shunichi Yamamoto
 */

#include "audio_control.h"
#include "ui_control_internal.h"

#include "adc.h"
#include "gpdma.h"
#include "hpdma.h"
#include "i2c.h"
#include "linked_list.h"
#include "sai.h"
#include "sai.h"
#include "eeprom.h"

#include "FreeRTOS.h"  // for xPortGetFreeHeapSize
#include "cmsis_os2.h"
#include "task.h"

#include "ak4619.h"
#include "adau1466.h"
#include "SigmaStudioFW.h"

#define N_SAMPLE_RATES TU_ARRAY_SIZE(sample_rates)
#define AUDIO_DIAG_LOG 0
#define DBG_MIN_U32_INIT UINT32_MAX

enum
{
    AUDIO_TASK_STATS_PERIOD_MS = 1000u,
    AUDIO_BYTES_PER_SAMPLE_32  = 4u,
    AUDIO_USB_FRAME_CHANNELS   = 4u,
    AUDIO_RING_FRAME_WORDS     = 4u,
    DBG_MIN_U16_INIT           = 0xFFFFu,
    AUDIO_USB_HS_MICROFRAMES_PER_SECOND = 8000u,
    AUDIO_FUNC_ID              = 0u,
};

extern DMA_QListTypeDef List_GPDMA1_Channel2;
extern DMA_QListTypeDef List_GPDMA1_Channel3;
extern DMA_QListTypeDef List_HPDMA1_Channel0;

enum
{
    BLINK_STREAMING   = 25,
    BLINK_NOT_MOUNTED = 250,
    BLINK_MOUNTED     = 1000,
    BLINK_SUSPENDED   = 2500,
};

enum
{
    VOLUME_CTRL_0_DB    = 0,
    VOLUME_CTRL_50_DB   = 12800,
};

// Audio controls
static uint32_t tx_blink_interval_ms = BLINK_NOT_MOUNTED;
static uint32_t rx_blink_interval_ms = BLINK_NOT_MOUNTED;

volatile uint32_t sai_tx_rng_buf_index = 0;
volatile uint32_t sai_rx_rng_buf_index = 0;
volatile uint32_t sai_transmit_index   = 0;
volatile uint32_t sai_receive_index    = 0;

static volatile uint8_t tx_pending_mask = 0;      // bit0: first-half, bit1: second-half
static volatile uint8_t rx_pending_mask = 0;      // bit0: first-half, bit1: second-half
static volatile bool usb_tx_pending     = false;  // USB TX送信要求フラグ (ISR→Task通知用)
static volatile bool usb_rx_pending     = false;  // USB RX受信通知フラグ (ISR→Task通知用)
static TaskHandle_t s_audio_task_handle = NULL;

void audio_control_register_task(void)
{
    s_audio_task_handle = xTaskGetCurrentTaskHandle();
}

static inline void audio_task_notify(void)
{
    if (s_audio_task_handle == NULL)
    {
        return;
    }

    xTaskNotifyGive(s_audio_task_handle);
}

static inline void audio_task_notify_from_isr(void)
{
    if (s_audio_task_handle == NULL)
    {
        return;
    }

    BaseType_t xHigherPriorityTaskWoken = pdFALSE;
    vTaskNotifyGiveFromISR(s_audio_task_handle, &xHigherPriorityTaskWoken);
    portYIELD_FROM_ISR(xHigherPriorityTaskWoken);
}

#if AUDIO_DIAG_LOG
static volatile uint32_t dbg_tx_used_min            = 0xFFFFFFFFu;
static volatile uint32_t dbg_tx_used_max            = 0u;
static volatile uint32_t dbg_tx_underrun_events     = 0u;
static volatile uint32_t dbg_tx_partial_fill_events = 0u;
static volatile uint32_t dbg_tx_drift_up_events     = 0u;
static volatile uint32_t dbg_tx_drift_dn_events     = 0u;
static volatile uint32_t dbg_usb_read_zero_events   = 0u;
static volatile uint32_t dbg_usb_read_bytes         = 0u;
static volatile uint32_t dbg_dma_err_events         = 0u;
static volatile uint32_t dbg_sai_tx_err_events      = 0u;
static volatile uint32_t dbg_sai_rx_err_events      = 0u;
static volatile uint32_t dbg_sai_tx_last_err        = 0u;
static volatile uint32_t dbg_sai_rx_last_err        = 0u;
static volatile uint32_t dbg_sai_tx_sr_flags        = 0u;
static volatile uint32_t dbg_sai_rx_sr_flags        = 0u;
static uint32_t dbg_sigma_calls_prev                = 0u;
static uint32_t dbg_sigma_err_prev                  = 0u;
static uint32_t dbg_sigma_to_prev                   = 0u;
static uint32_t dbg_sigma_mto_prev                  = 0u;
static volatile uint32_t dbg_tx_half_rewrite_events = 0u;
static volatile uint32_t dbg_tx_cplt_rewrite_events = 0u;
static volatile uint32_t dbg_rx_half_rewrite_events = 0u;
static volatile uint32_t dbg_rx_cplt_rewrite_events = 0u;
static volatile uint16_t dbg_usb_read_size_min      = DBG_MIN_U16_INIT;
static volatile uint16_t dbg_usb_read_size_max      = 0u;
static volatile uint32_t dbg_usb_out_packet_events  = 0u;
static volatile uint32_t dbg_usb_out_packet_bytes   = 0u;
static volatile uint16_t dbg_usb_out_packet_size_min = DBG_MIN_U16_INIT;
static volatile uint16_t dbg_usb_out_packet_size_max = 0u;
static volatile uint32_t dbg_usb_out_gap_cycles_min = DBG_MIN_U32_INIT;
static volatile uint32_t dbg_usb_out_gap_cycles_max = 0u;
static volatile uint32_t dbg_usb_out_gap_late_events = 0u;
static volatile uint32_t dbg_usb_out_prev_cycle     = 0u;
static volatile bool dbg_usb_out_prev_cycle_valid   = false;
static volatile uint32_t dbg_usb_out_coalesced_events = 0u;
static volatile uint32_t dbg_usb_out_pending_cycle  = 0u;
static volatile uint32_t dbg_usb_out_service_cycles_min = DBG_MIN_U32_INIT;
static volatile uint32_t dbg_usb_out_service_cycles_max = 0u;
static volatile uint16_t dbg_usb_out_fifo_min       = DBG_MIN_U16_INIT;
static volatile uint16_t dbg_usb_out_fifo_max       = 0u;
static volatile uint32_t dbg_usb_in_packet_events   = 0u;
static volatile uint32_t dbg_usb_in_packet_zero_events = 0u;
static volatile uint32_t dbg_usb_in_packet_bytes    = 0u;
static volatile uint16_t dbg_usb_in_packet_size_min = DBG_MIN_U16_INIT;
static volatile uint16_t dbg_usb_in_packet_size_max = 0u;
static volatile uint32_t dbg_usb_in_notify_events   = 0u;
static volatile uint32_t dbg_usb_in_source_wait_events = 0u;
static volatile uint32_t dbg_usb_in_write_zero_events = 0u;
static volatile uint32_t dbg_usb_in_write_partial_events = 0u;
static volatile uint32_t dbg_usb_in_write_bytes     = 0u;
static volatile uint16_t dbg_usb_in_fifo_min        = DBG_MIN_U16_INIT;
static volatile uint16_t dbg_usb_in_fifo_max        = 0u;

static uint32_t audio_diag_cycles_to_us(uint32_t cycles)
{
    if (SystemCoreClock == 0u)
    {
        return 0u;
    }

    return (uint32_t) ((((uint64_t) cycles * 1000000u) + (SystemCoreClock / 2u)) / SystemCoreClock);
}
#endif

bool s_streaming_out = false;
bool s_streaming_in  = false;

static volatile bool is_sr_changed = false;

const uint32_t sample_rates[] = {48000, 96000};
static volatile uint32_t current_sample_rate = 48000U;

__attribute__((section("noncacheable_buffer"), aligned(32))) int32_t usb_out_buf[CFG_TUD_AUDIO_FUNC_1_EP_IN_SW_BUF_SZ / 4] = {0};
__attribute__((section("noncacheable_buffer"), aligned(32))) int32_t usb_in_buf[CFG_TUD_AUDIO_FUNC_1_EP_OUT_SW_BUF_SZ / 4] = {0};

__attribute__((section("noncacheable_buffer"), aligned(32))) int32_t sai_tx_rng_buf[SAI_RNG_BUF_SIZE] = {0};
__attribute__((section("noncacheable_buffer"), aligned(32))) int32_t sai_rx_rng_buf[SAI_RNG_BUF_SIZE] = {0};

__attribute__((section("noncacheable_buffer"), aligned(32))) int32_t stereo_out_buf[SAI_TX_BUF_SIZE] = {0};
__attribute__((section("noncacheable_buffer"), aligned(32))) int32_t stereo_in_buf[SAI_RX_BUF_SIZE]  = {0};

// Speaker data size received in the last frame
uint16_t spk_data_size;
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

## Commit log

2025-04-05 Added KiCad project files.
    [OTO_NO_ITA.kicad_pcb, OTO_NO_ITA.kicad_sch, dsp.kicad_sch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]
2025-04-07 Updated schematics.
    [OTO_NO_ITA.kicad_sch, dsp.kicad_sch, mcu.kicad_sch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]
2025-04-10 Assigned footprint.
    [dsp.kicad_sch, mcu.kicad_sch, usb.kicad_sch]
2025-04-10 Updated pcb.
    [OTO_NO_ITA.kicad_pcb]
2025-04-11 Added USER_SW.
    [mcu.kicad_sch]
2025-04-11 Update parts layout.
    [OTO_NO_ITA.kicad_pcb]
2025-04-17 Routed Power, USB and PSRAM.
    [OTO_NO_ITA.kicad_pcb]
2025-04-18 Change the order of IO assignment to pin headers.
    [dsp.kicad_sch, mcu.kicad_sch]
2025-04-18 Routed all path.
    [OTO_NO_ITA.kicad_pcb]
2025-04-21 Changed the footprint size of R14.
    [usb.kicad_sch]
2025-04-21 Assigned Part No. of JLCPCB.
    [OTO_NO_ITA.kicad_pcb]
2025-04-21 Assigned JLCPCB's Part No. of Q2 and Q3.
    [OTO_NO_ITA.kicad_pcb]
2025-04-21 Changed layer from 4 to 6.
    [OTO_NO_ITA.kicad_pcb]
2025-04-23 Modified wiring between ICs.
    [OTO_NO_ITA.kicad_sch, dsp.kicad_sch, mcu.kicad_sch]
2025-04-23 Improved board design.
    [OTO_NO_ITA.kicad_pcb]
2025-04-23 Improved GND plane.
    [OTO_NO_ITA.kicad_pcb]
2025-04-23 Modified the date.
    [OTO_NO_ITA.kicad_pcb]
2025-04-24 Added some resistors and Schottky diode.
    [OTO_NO_ITA.kicad_pcb, dsp.kicad_sch, mcu.kicad_sch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]
2025-04-24 Assigned JLCPCB's part No.
    [OTO_NO_ITA.kicad_pcb]
2025-04-30 Modified the pin header J6 for USBi.
    [OTO_NO_ITA.kicad_pcb, dsp.kicad_sch]
2025-05-02 Change J7 and J8(5V in/out connector) to JST PH.
    [OTO_NO_ITA.kicad_pcb, usb.kicad_sch]
2025-05-09 Improved some routes.
    [OTO_NO_ITA.kicad_pcb, OTO_NO_ITA.kicad_sch, mcu.kicad_sch]
2025-05-13 Fixed some JLCPCB part No.
    [OTO_NO_ITA.kicad_pcb]
2025-05-16 Fixed U2 footprint.
    [OTO_NO_ITA.kicad_pcb]
2025-05-23 Fixed some mistakes.
    switched 5V and 5V_UCPD.
    switched VREFP and VREFM.
    [OTO_NO_ITA.kicad_pcb, mcu.kicad_sch, power.kicad_sch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]
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2025-06-08 Add the project which LED blinking from Appli code.
    [LED_BLINK_APP_Boot.cfg]
2025-06-18 Add the project which the USB test.
    [LED_BLINK_APP_Boot.cfg]
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2025-07-28 Added AK4619 codec test board project.
    [OTO_NO_DEIRI.kicad_pcb, OTO_NO_DEIRI.kicad_sch]
2025-08-19 Changed pin assignments for J4 and J6.
    [OTO_NO_ITA.kicad_pcb, dsp.kicad_sch, mcu.kicad_sch]
2025-08-19 Added exported system files.
    [oto_no_ita_dsp_ADAU146xSchematic_1.param]
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2026-03-03 フェーダーのカーブをスクラッチ向きにしたときに正しく動作するよう修正
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2026-03-03 コメントの文字化けを修正
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2026-03-03 内容を修正
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2026-03-04 Parametric EQによるRIAA近似を廃止し、固定Biquadに置き換え
    [JUMBLEQ_DSP_ADAU146xSchematic_1.param]
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2026-03-05 Mac/iPadに接続した際に、タスクの初期化中にフリーズする不具合を修正
    - あるタスクの初期化中に別タスクの初期化が実施されないようにする
    - AUDIO、LED、ADC、OLED、USBの順で初期化を行う
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2026-03-05 Biquadフィルタ後段に2次Butterworth HPF(20Hz)を追加
    [JUMBLEQ_DSP_ADAU146xSchematic_1.param]
2026-03-05 Butterworthの位置をBiquadの前段に変更
    [JUMBLEQ_DSP_ADAU146xSchematic_1.param]
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2026-03-05 【SigmaStudio+】USBから戻ってくる経路にVolumeブロックを追加
    [JUMBLEQ_DSP_ADAU146xSchematic_1.param]
2026-03-06 【SigmaStudio+】USB入力用のVolumeブロックを1チャンネルごとに置く
    [JUMBLEQ_DSP_ADAU146xSchematic_1.param]
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2026-03-06 マスターボリュームを廃止し、Ch.1/2それぞれの出力ボリュームを追加
    [JUMBLEQ_DSP_ADAU146xSchematic_1.param]
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2026-03-07 アナログマルチプレクサの配線修正と部品番号を整理
    [OTO_NO_TE.kicad_pcb, OTO_NO_TE.kicad_sch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]
2026-03-09 Remove kicad projects
    [BOM-OTO_NO_TE.csv, OTO_NO_ITA.kicad_pcb, OTO_NO_ITA.kicad_sch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]
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2026-03-10 ダンプしたパラメータがUIに正しく反映されるよう修正
2026-03-12 READMEの構成整理とハードウェア・Errata対策情報の追記
    ドキュメントの構成を分かりやすく整理するため、セクションの順序変更と「Modules」から「Hardware」への名称変更を行いました。また、STM32H7S3のエラッタ(2.2.15)に対する回避策の実装に関する情報を追加しました。
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2026-03-19 Dry/WetでミックスするReturnのソースをUSB12かUSB34か切り替えるためのスイッチを追加
    [JUMBLEQ_DSP_ADAU146xSchematic_1.param]
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2026-03-20 DVS有効時にホストに送る信号にXF通過後の信号を混ぜていた不具合を修正
    [JUMBLEQ_DSP_ADAU146xSchematic_1.param]
2026-03-20 SPIの設定をADAU1466の推奨設定に修正
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2026-03-20 サンプルレート切り替え時にADAU1466を必ずリセットするよう修正
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2026-03-20 名称修正
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2026-03-21 デバイス起動直後、XF-Aにアサインした音がフェーダーオフでも鳴ってしまう不具合を修正
    [JUMBLEQ_DSP_ADAU146xSchematic_1.param]
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2026-03-24 UI制御関連の定数整理およびポットのマッピング修正
    - audio_control.h に定義されていたUI関連の定数を ui_control.c/h 側に移動
    - ポット用マルチプレクサのビットテーブルをインデックス順に整理し、ADC値読み取り時のチャンネル判定処理を更新
    - MAG_XFADE_RANGE の値を 850 から 1400 に調整
    [ui_control.c]
2026-03-24 ポット入力にヒステリシス処理を追加
    ADC値の微小な変動による値の振らつきを抑制するため、移動平均と閾値を用いたヒステリシス判定ロジックを導入しました。あわせて、移動平均の計算においてバッファが埋まる前のサンプル数も正しく扱うよう修正しています。
2026-03-24 VUメーターのdBFS計算式を修正
    SigmaDSPの8.24固定小数点形式（Unity gain = 0x01000000）に合わせてフルスケール値を修正し、対数計算を自然対数から常用対数（log10f）に変更しました。
    [led_control.c]
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2026-04-02 【Plasticity】Ignore 3D model files and Plasticity workspace
    Add *.3mf, *.stp, and the Plasticity local directory to .gitignore to prevent tracking of 3D design assets and local workspace files.
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2026-04-06 【SigmaStudio+】SDATA_OUT2をTAD5142用に設定
    ｰ AK4619の2系統と同じ音を出力させる（仮）
    [JUMBLEQ_DSP_ADAU146xSchematic_1.param]
2026-04-06 ビットシフト時にオーバーフローしないよう修正
    SigmaDSPのRead Blockのデータ列をuint32_tで明示的にキャストしてから扱う
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2026-04-07 【SigmaStudio+】HPに出力するソース選択ブロックを追加
    [JUMBLEQ_DSP_ADAU146xSchematic_1.param]
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2026-04-09 【SigmaStudio+】HP出力するソースを整理
    XF_A、XF_B、THRU、Masterの4つに変更
    [JUMBLEQ_DSP_ADAU146xSchematic_1.param]
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2026-04-13 POT操作時に設定最大値に到達しない不具合を修正
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2026-04-13 POTの並びと配列の割り当ての不整合を修正
2026-04-13 変数名を修正し、OLEDの表示順を物理的な並びに合わせる
2026-04-13 POT割り当て変更に伴うOLED表示とヒステリシス処理の整合修正
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2026-04-14 サンプルレート変更時にUIの状態を正しく反映するように修正 #71
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2026-04-16 UF2書き込み完了後にリセットするよう修正
    - UF2コピー完了後のアプリ直接ジャンプをやめる
    - UF2完了または書き込み停止を検出後、少し待ってからリセットする
    - 通常起動経由で更新後アプリが起動するようにする
    - finalize処理を通さず、書き込み後の停止を回避する
    [main.c]
2026-04-16 UF2書き込み完了後はfinalizeせずリセットするよう修正
    - UF2更新後のCRC/metadata finalize処理を廃止
    - finalize中の外部Flash Read停止を回避
    - UF2コピー完了または書き込み停止検出後に通常リセットする
    - 更新後アプリはリセット後の通常起動経由で開始する
2026-04-16 パスの修正
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2026-04-17 オーディオのルーティング図を修正
    - HP MONITOR SEL周辺をわかりやすく整理
    - 凡例を追加
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2026-04-21 M4LをMax for Liveに修正
2026-04-21 【SigmaStudio+】Phono経路のゲイン調整
    - フォノEQ後に持ち上げていたゲインを+48dBから+9dBに下げる
    [JUMBLEQ_DSP_ADAU146xSchematic_1.param]
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2026-04-21 筐体の各パーツの3Dモデルデータを追加
    [enclosure.stp, key_plate.stp, middle_plate.stp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]
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2026-04-22 タイトルを修正
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2026-04-22 Top Plateのデザインデータを追加
    [JUMBLEQ_top_panel_outline.dxf]
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2026-04-28 fade-downを離したときに音漏れが発生する不具合を修正
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2026-05-29 HP OUTの出力ゲインをADAU1466の最終段で+2dBする
    [JUMBLEQ_DSP_ADAU146xSchematic_1.param]
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2026-07-30 USB bcdDeviceを有効なBCD形式で生成
    USBデバイス版数をM.m.pp形式のBCD値として生成する。
    v0.9.11のbcdDeviceを0x0911に修正する。
    BCDで表現できないバージョンをビルド時に検出する。
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2026-07-30 feat(dsp): add 25 Hz fourth-order phono high-pass filters
    [JUMBLEQ_DSP_ADAU146xSchematic_1.param]
2026-07-30 96kHz切り替え時のADAU1466 SPIバッファオーバーフローを修正
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2026-08-05 ADAU1466を96kHzコア固定のASRC構成に変更
    - 48kHz USB入出力をASRC経由に変更
    - 96kHz用Direct経路と一括切り替えスイッチを追加
    - SigmaStudio+生成データとSTM32組み込みヘッダーを更新
    [JUMBLEQ_DSP_ADAU146xSchematic_1.param]
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2026-08-05 refactor(dsp): 出力段のSplitterを削除
    SigmaStudio+の直接分岐に置き換え、DSPプログラムと生成ヘッダーを更新
    [JUMBLEQ_DSP_ADAU146xSchematic_1.param]
2026-08-05 refactor(dsp): Line/Phono経路のMergerをSignal Addに変更
    自動減衰を廃止し、フォノイコライザー後段のゲインを+3dBに調整
    [JUMBLEQ_DSP_ADAU146xSchematic_1.param]
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2026-08-06 クロスフェーダー制御信号にDVS補正用Delayを追加
    - クロスフェーダーA/Bの制御信号経路にDelayを追加
    - 最大遅延を20ms、初期値を0msに設定
    - DSPプログラムとパラメータ定義を再Export
    [JUMBLEQ_DSP_ADAU146xSchematic_1.param]
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2026-08-06 fix: fade-up保持中のfade-down入口側フェードを無効化
    fade-up起点時はfade-down押下途中の連続フェードを抑止する。全押下側のhard cutとbottom-hold処理、およびfade-up未押下時のfade-down動作は維持する。
    [ui_control.c]
2026-08-08 SigmaStudio+: DVS DelayとクロスフェーダーExtVol設定を更新
    - Delay A/Bの最大遅延を100msへ拡張
    - Delay Curの初期値を0msに設定
    - ExtVol A/BのFade-In/OutをLinearへ変更
    - ExtVol A/BのSlew Rateを1へ変更
    - DSPプログラムとexportデータを更新
    [JUMBLEQ_DSP_ADAU146xSchematic_1.param]
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2026-08-17 不用なBootとExtLoaderを削除
    [LED_BLINK_APP_Boot.cfg]
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2026-08-18 ST-LINKデバッグ設定ドキュメントに概要を追加
    - 見出しを文書タイトルの階層に修正
    - スクリーンショットの用途を説明
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2026-08-19 fix: fade-up保持中もfade-downカーブを双方向に適用
    fade-up起点の同時操作でも設定したカーブを反映する。
    bottom到達後の復帰時にもdown_gainを適用し、瞬間的な出力上昇を防止する。
    [ui_control.c]
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2026-08-19 fix: Restore defaultsと初期表示の設定値を統一
    - Channel 2 inputをLINEに変更
    - Post faderをUSB 1/2に変更
    - DVS Channel 1をDisabledに変更
    - CrossfaderカーブA/Bを50%に変更
    - 共通の初期設定をRestore defaultsと未接続時表示へ適用
2026-08-19 fix: 入力切替カードの表記を改善
    - INPUT CHANNEL 1/2をINPUT SELECT SWITCHへ変更
    - チャンネル番号を1/2のバッジで表示
    - 重複していたChannel 1/2見出しを削除
    - 見出しと入力選択ボタンの余白を調整
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2026-08-20 fix: ファームウェアの初期値をRestore Defaultsに統一
    - Fader Aの初期割り当てをCH 1に変更
    - Fader Bの初期割り当てをCH 2に変更
    - Crossfader Curve A/Bの初期値を50％に変更
    - EEPROM未初期化時とUI状態リセット時の既定値を統一
    [eeprom.c, ui_control.c]
2026-08-20 fix: 未接続時の表示とControls説明文を改善
    - Demo modeをOfflineへ変更
    - 未接続時のデバイス名からdemo表記を削除
    - Controlsセクションの対象機能が分かる説明文へ変更
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2026-08-20 画像のリンクを修正
    Updated image sources and sizes in the configurator documentation.
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2026-08-24 docs: フェーダー関連の用語をChannel Faderに統一
    CrossfaderおよびXFader表記をChannel Faderに置き換え、
    ヘッドホン出力の列挙名をFADER_A/Bに更新する。
    あわせて、カーブの既定CC値を実装に合わせて
    Channel Fader A/Bともに64へ修正する。
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2026-08-25 【SigmaDSP/Appli】DVSフェーダー制御のDelayブロックを削除
    - SigmaStudio+からDelay_A/Bを削除
    - DSPプログラムとパラメータを再生成
    - Delay設定APIと割り当て変更時の更新処理を削除
    - 大容量のDM1初期化データを削減
    [JUMBLEQ_DSP_ADAU146xSchematic_1.param]
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2026-08-26 fix: ST-LINKデバッグでRelease版Boot ELFを参照
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2026-08-26 Return無効時のDry/Wet動作とOLED表示を修正
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2026-09-02 DSP回路の見出しを修正
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2026-09-03 Reverse設定のMIDI・EEPROM・OLED対応を追加
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2026-09-07 ReleaseビルドのUF2生成とリンカースクリプトのパスを修正
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

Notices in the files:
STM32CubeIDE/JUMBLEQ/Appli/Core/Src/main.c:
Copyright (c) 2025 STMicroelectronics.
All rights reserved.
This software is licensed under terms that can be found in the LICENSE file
